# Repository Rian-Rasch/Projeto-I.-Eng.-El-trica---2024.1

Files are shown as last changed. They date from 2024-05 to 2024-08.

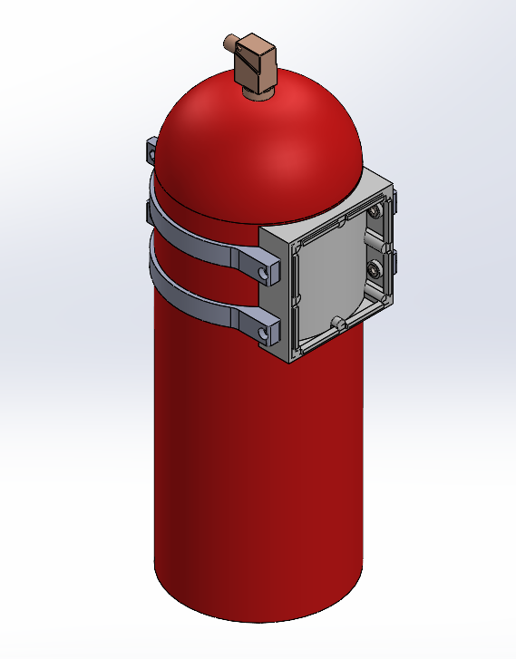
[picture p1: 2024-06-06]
Imagens Guia/Montagem com abraçadeiras.PNG

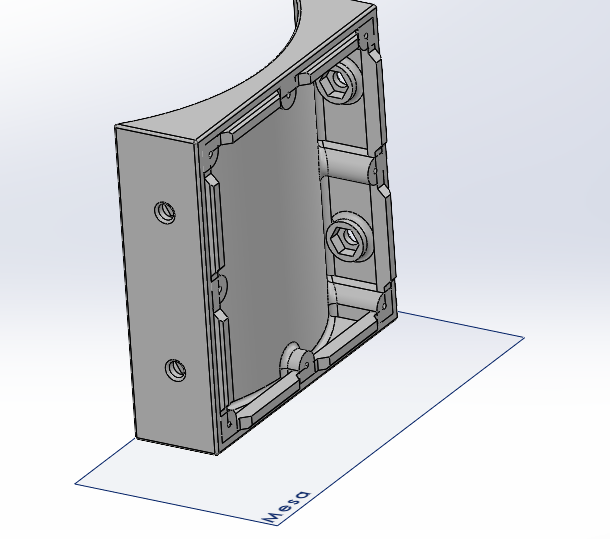
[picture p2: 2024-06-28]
Modelagens/envio para impressão/EXA104/Sentido de impressão.PNG

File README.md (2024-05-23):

# Project I. Electrical Engineering | 2024.1
# Development of an Automatic Fire Extinguisher System with Fire Detection

## Introduction:
This project is developed as part of the Integrative Project course. The main objective is to design and implement an automatic fire extinguisher system capable of detecting fires using Arduino, with the aim of improving traditional fire-fighting systems.

## Objectives:
1. Design an automatic fire extinguisher system capable of accurately and quickly detecting fires using Arduino.
2. Develop an automatic extinguishing mechanism that is effective in suppressing fires.
3. Evaluate the effectiveness and technical feasibility of the system in different fire scenarios.

## Methodology:
To achieve the proposed objectives, the following steps were adopted:
1. Literature review to understand the principles of fire detection and existing automatic extinguishing systems.
2. Conceptual design of the system, considering detection requirements, extinguishing agents, and system integration using Arduino.
3. Implementation of the system in a laboratory environment, using Arduino, fire detection sensors, and extinguishing mechanisms.
4. Testing and analysis to evaluate the effectiveness of the system under different fire conditions.

## Expected Results:
It is expected that this project will result in an effective, reliable, and economically viable automatic fire extinguisher system based on Arduino. Additionally, it aims to contribute to the advancement of fire-fighting technology, offering an innovative solution adaptable to various applications.

## Conclusion:
We believe that this project represents a significant contribution to fire safety, providing a solution that combines advanced fire detection with automatic extinguishing using the Arduino platform. We look forward to sharing our results and discussing potential improvements and future applications.

Thank you for your attention.

---

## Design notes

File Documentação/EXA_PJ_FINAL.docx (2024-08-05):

EXA: Extintor Automático contra

incêndios em quadros elétricos

Rian Rasch PereiraI, Mateus da Rosa TonettoI,

Marcus Vinicius Preira dos SantosI, Theo do Nascimento MoreiraI

I Universidade Federal de Santa Maria, Santa Maria, Rio Grande do Sul, Brasil

RESUMO

Ao pensarmos no combate de incêndios elétricos também estamos examinando perdas humanas, patrimoniais e afetivas, bem como a devastação da fauna e flora locais, graves interrupções no fornecimento de energia e risco iminente de incêndios de maior magnitude. Um ponto crítico, em qualquer infraestrutura são os quadros elétricos, e a instalação de um dispositivo que age com resposta imediata aos incêndios e está diretamente interligado ao sistema elétrico, pode facilitar o combate ao incêndio, minimizando os danos. Por este motivo o presente trabalho tem por objetivo elaborar o dispositivo EXA para a extinção de incêndios automatizada em quadros elétricos. Para isso, foram realizados estudo laboratoriais com Arduino, sensores de temperatura e infravermelho, bem como, a criação de um código.

Palavras-chave: Automação; Extintor; Prevenção a incêndio; Quadro de distribuição; Quadro elétrico

ABSTRACT

When considering the combat of electrical fires, we are also examining human, material, and emotional losses, as well as the devastation of local fauna and flora, severe interruptions in energy supply, and the imminent risk of larger fires. A critical point in any infrastructure is the electrical panels, and the installation of a device that acts with immediate response to fires and is directly interconnected with the electrical system can facilitate fire fighting, minimizing damages. For this reason, the present study aims to develop the EXA device for automated fire extinguishing in electrical panels. To achieve this, laboratory studies were conducted with Arduino, temperature and infrared sensors, as well as the creation of a code.

Keywords: Automation; Extinguisher; Fire Prevention; Electrical Panel; Distributionm Panel;

1 INTRODUÇÃO

A segurança contra incêndios elétricos é uma questão de extrema importância em diversos setores, desde residências até indústrias. A cada ano, milhares de incidentes de incêndios elétricos ocorrem em todo o mundo, resultando em perdas significativas de vidas, propriedades e recursos naturais. Segundo dados da Associação Brasileira de Conscientização para os Perigos da Eletricidade (Abracopel)¹, somente em 2023 foram registrados 963 casos de incêndios elétricos no Brasil, o que evidencia a urgência em desenvolver e implementar medidas eficazes de prevenção e combate a esses eventos.

Neste contexto, o desenvolvimento do Extintor Automático Contra Incêndio em Quadros Elétricos (EXA) representa um novo olhar, com mais atenção para a segurança de sistemas elétricos. O EXA é um dispositivo projetado especialmente para quadros de distribuição, capaz de detectar rapidamente fogo ou calor excessivo e acionar uma descarga de CO2 para extinguir o incêndio de forma automatizada [2].

A presente pesquisa tem como objetivo explorar as características, funcionamento e eficácia do EXA como medida de prevenção e combate a incêndios elétricos em quadros elétricos. Para isso, serão realizados estudos laboratoriais com Arduino, sensores de temperatura e infravermelho, além da análise de dados de ocorrências de incêndios elétricos para embasar empiricamente os resultados obtidos.

2 MATERIAIS E MÉTODOS

Os materiais utilizados para a construção do projeto EXA foram: o Módulo Sensor de Chamas KY-026, o Módulo Sensor de Temperatura KY-028, pequenos condutores, um extintor de CO2 de 6 quilos, um display genérico 16x2 (com IC2), parafusos, três baterias de Lítio 18650, uma placa BMS, um servo motor, conjunto de cabo de aço e conduite, fonte de alimentação bivolt 12V, um quadro elétrico, um Arduino. Além disso com auxílio do programa Solid Works foram modelados: uma Caixa Corpo EXA101 (Anexo 2), a Tampa 1 – Caixa EXA102 (Anexo 3), Tampa 2 – Caixa EXA104 (Anexo 4), 04 braçadeiras EXA301 (Anexo 5), um Suporte Servomotor EXA230 (Anexo 6), uma Polia Motora EXA 231 (Anexo 7), o Suporte Sensores EXA 200 (Anexo 8). Podemos conferir a Montagem Caixa – Tampas no Anexo 8.

Foi utilizado a linguagem de programação C++ e o ambiente laboratorial NUPEDEE do Centro de Tecnologias da Universidade Federal de Santa Maria para criar o código abaixo:

1 #include <Wire.h> // Biblioteca para Comunicação I2C
2 #include <LiquidCrystal_I2C.h> // Biblioteca com as funções do display
3 #include <Servo.h>
5 #define flameSensorPin A0
6 #define tempSensorPin A1
7 #define batterySensorPin A2 // Supondo que o sensor de carga da bateria está conectado ao pino A2
8 #define servoPin 3
10 #define p_temp 60
11 #define p_fogo 200
12 Servo servo;
14 LiquidCrystal_I2C lcd(0x27,20,4); // Inicializa o display no endereço 0x27
16 void setup() {
17 Serial.begin(9600);
18 servo.attach(servoPin);
19 servo.write(0);
20 lcd.init();
21 lcd.begin(16, 2); // Identifica que o display possui 16 colunas e 2 linhas
22 lcd.clear(); // Apaga todos os caracteres do Display
23 lcd.backlight();
24 }
26 int fogo_ir() {
27 if (analogRead(flameSensorPin) < p_fogo) {
28 delay(250);
29 if (analogRead(flameSensorPin) < p_fogo) {
30 return 1;
31 } else return 0;
32 }
33 } else {
34 return 0;
35 }
36 }
38 int fogo_temp() {
39 if (map(analogRead(tempSensorPin), 0, 1023, 125, -55) > p_temp) {
40 delay(250);
41 if (map(analogRead(tempSensorPin), 0, 1023, 125, -55) > p_temp) {
42 return 1;
43 } else {
44 return 0;
45 }
46 } else {
47 return 0;
48 }
49 }
51 void aciona_ext(int flag){
52 int tempo = flag * 1000;
53 servo.write(360);
54 delay (tempo);
55 servo.write(0);
56 }
58 void loop() {
59 int flag = fogo_temp() + fogo_ir();
60 /*
61 Serial.print("Flag = ");
62 Serial.println(flag);
64 Serial.print("Temperatura: ");
65 Serial.print(map(analogRead(tempSensorPin), 0, 1023, 125, -55));
66 Serial.println(" C ");
68 Serial.print("Bat: ");
69 Serial.print(map(analogRead(batterySensorPin), 0, 1023, 0, 100));
70 Serial.println("%");
72 Serial.println();
73 */
74 delay(1000);
76 lcd.clear(); // Apaga todos os caracteres do Display
77 lcd.setCursor(0,0); // Marca o cursor na posição coluna 0, linha 0
78 lcd.print("Temperatura:");
79 lcd.print(map(analogRead(tempSensorPin), 0, 1023, 125, -55));
80 lcd.print("C");
82 lcd.setCursor(0,1); // Marca o cursor na posição coluna 0, linha 1
83 lcd.print("Bat:");
84 lcd.print(map(analogRead(batterySensorPin), 0, 1023, 0, 100));
85 lcd.print("%");
86 lcd.print(" Ir: ");
87 lcd.print(analogRead(flameSensorPin));
88 }

O funcionamento do Projeto consta como na Figura 1. Os sensores acoplados ao quadro de distribuição e ligados a um Arduino, quando detectarem 60 GRAUS, fogo ou infravermelho farão com que o servo motor receba um sinal, sendo ativado e liberando uma descarga de CO2, até que sesse o sinal de fogo (O Extintor tem de 13 a 18 s de funcionamento em abertura total, não sei como inserir isso aqui ). O servo motor é inserido dentro da Caixa de Corpo, que fica integrado ao extintor de incêndio através de duas braçadeiras conforme a Figura 2.

Figura 1 – Diagrama de funcionamento do projeto

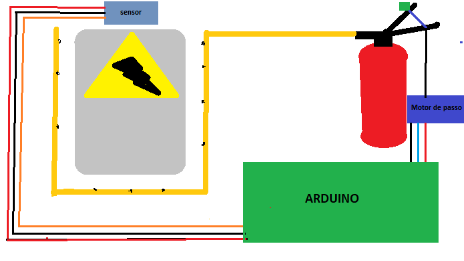
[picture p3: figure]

Fonte: desenvolvida pelos autores

Figura 2 – Ilustração do extintor

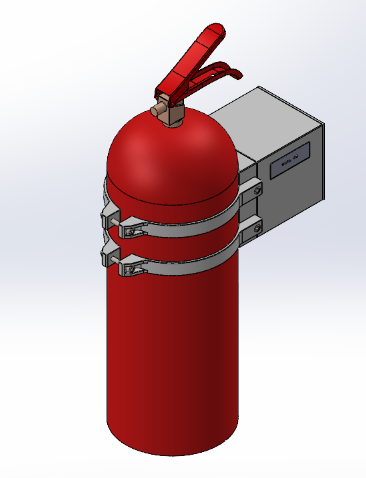
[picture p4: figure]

Fonte: desenvolvido pelos autores

3 RESULTADOS E DISCUSSÃO

BLÁ BLÁ FONTE 12 0.5 DE PARAGRAFO

Colocar foto das coisas montadas

Depois que terminar, salva o PDF e mescla com os anexos

4 CONCLUSÃO

BLÁ BLÁ FONTE 12 0.5 DE PARAGRAFO. Não pode ter referencias aqui, cuidado

REFERÊNCIAS

1 - MARTINHO, Edson; DE SOUZA, Danilo Ferreira; MARTINHO, Meire Biudes; MARTINS JR. Walter Aguiar; MORITA, Lia Hanna Martins; MAIONCHI, Daniela de Oliveira (org). ANUÁRIO ESTATÍSTICO DE ACIDENTES DE ORIGEM ELÉTRICA 2024 – Ano base 2023. Salto-SP: Abracopel, 2023. DOI: 10.29327/

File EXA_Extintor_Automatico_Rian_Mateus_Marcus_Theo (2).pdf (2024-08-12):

# EXA: Extintor Automático contra incêndios em quadros elétricos

Rian Rasch Pereira
Federal University of Santa Maria, UFSM Santa Maria, Brazil
rian.rasch@acad.ufsm.br

Mateus da Rosa Tonetto
Federal University of Santa Maria, UFSM Santa Maria, Brazil
mateus.tonetto@acad.ufsm.br

Theo do Nascimento Moreira Federal University of Santa Maria, UFSM Santa Maria, Brazil
theo.moreira@acad.ufsm.br

Marcus Vinicius Preira dos Santos Federal University of Santa Maria, UFSM Santa Maria, Brazil
marcus.santos@acad.ufsm.br

Resumo — Ao pensarmos no combate de incêndios elétricos também estamos examinando perdas humanas, patrimoniais e afetivas, bem como a devastação da fauna e flora locais, graves interrupções no fornecimento de energia e risco iminente de incêndios de maior magnitude. Um ponto crítico, em qualquer infraestrutura são os quadros elétricos, e a instalação de um dispositivo que age com resposta imediata aos incêndios e está diretamente interligado ao sistema elétrico, pode facilitar o combate ao incêndio, minimizando os danos. Por este motivo o presente trabalho tem por objetivo elaborar o dispositivo EXA para a extinção de incêndios automatizada em quadros elétricos. Para isso, foram realizados estudo laboratoriais com Arduino, sensores de temperatura e infravermelho, bem como, a criação de um código.

Palavras-chaves— | Automação; | Extintor; | Prevenção | a
incêndio; Quadro de distribuição; Quadro elétrico.

Abstract — When considering the combat of electrical fires, we are also examining human, material, and emotional losses, as well as the devastation of local fauna and flora, severe interruptions in energy supply, and the imminent risk of larger fires. A critical point in any infrastructure is the electrical panels, and the installation of a device that acts with immediate response to fires and is directly interconnected with the electrical system can facilitate fire fighting, minimizing damages. For this reason, the present study aims to develop the EXA device for automated fire extinguishing in electrical panels. To achieve this, laboratory studies were conducted with Arduino, temperature and infrared sensors, as well as the creation of a code.

Keywords— Automação; Extintor; Prevenção a incêndio; Quadro de distribuição; Quadro elétrico.

I. INTRODUÇÃO

A segurança contra incêndios elétricos é uma questão de extrema importância em diversos setores, desde residências até indústrias. A cada ano, milhares de incidentes de incêndios elétricos ocorrem em todo o mundo, resultando em perdas significativas de vidas, propriedades e recursos naturais. Somente em 2023 foram registrados 963 casos de incêndios elétricos no Brasil, o que evidencia a urgência em desenvolver e implementar medidas eficazes de prevenção e combate a esses eventos. [1]
Neste contexto, o desenvolvimento do Extintor Automático contra incêndio em quadros elétricos (EXA) representa um novo olhar, com mais atenção para a segurança de sistemas elétricos. Este é um dispositivo projetado especialmente para quadros de distribuição, capaz de detectar rapidamente fogo ou calor excessivo e acionar uma descarga de CO2 para extinguir o incêndio de forma automatizada.
A presente pesquisa tem como objetivo explorar as características, funcionamento e eficácia do EXA como medida de prevenção e combate a incêndios em quadros elétricos, como projeto final da disciplina de Projeto Integrador em Engenharia Elétrica I (UFSM00295) da Universidade Federal de Santa Maria.

II. MATERIAIS E METODOS
Os materiais utilizados para a construção do projeto EXA foram: o Módulo Sensor de Chamas KY-026, o Módulo Sensor de Temperatura KY-028, pequenos condutores, um extintor de CO2 de 6 quilos, um display genérico 16x2 (com IC2), parafusos, três baterias de Lítio 18650, uma placa BMS, um servo motor, conjunto de cabo de aço e conduite, fonte de alimentação bivolt 12V, um quadro elétrico, um Arduino. Além disso com auxílio do programa Solid Works foram modelados: uma Caixa Corpo EXA101 (Anexo 1), a Tampa 1 – Caixa EXA102 (Anexo 2), Tampa 2 – Caixa EXA104 (Anexo 3), 04 braçadeiras EXA301 (Anexo 4), um Suporte Servomotor EXA230 (Anexo 5), uma Polia Motora EXA 231 (Anexo 6), o Suporte Sensores EXA 200 (Anexo 7). Podemos conferir a Montagem Caixa – Tampas (Anexo 8).

O quadro de apresentação foi retirado de uma sucata. Pelas condições do ambiente, havia muita sujeira e o desgaste da tinta. Por isso, foi necessário um reparo estético com tinta spray e uma intensa limpeza no material. Podemos observar na

Fig. 1 o quadro na situação em que foi encontrado e na Fig. 2 o quadro após sua restauração.

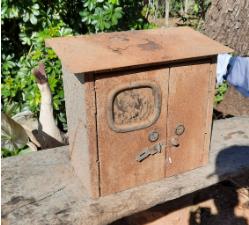
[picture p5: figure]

Fig.1 Quadro antes dos reparos estéticos

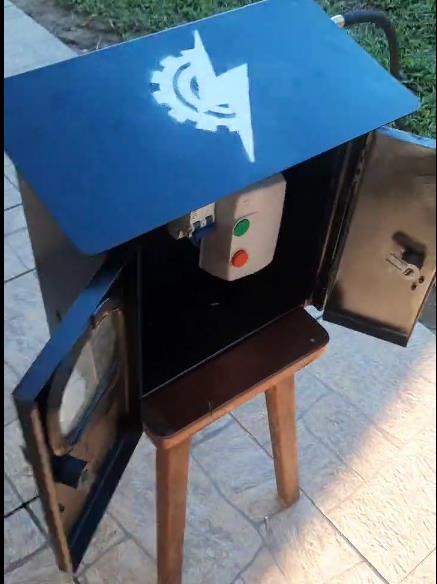
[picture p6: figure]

Fig. 2 Quadro após os reparos estéticos

Foi utilizado a linguagem de programação C++ e o ambiente laboratorial NUPEDEE do Centro de Tecnologias da Universidade Federal de Santa Maria para criar o código abaixo:
1 | #include <Wire.h>
2 | #include <LiquidCrystal_I2C.h>
3 | #include <Servo.h>
4
5 | #define flameSensorPin A0
6 | #define tempSensorPin A1
7 | #define batterySensorPin 2
8 | #define servoPin 3
9
10 | #define p_temp 60
11 | #define p_fogo 200 //0 a 1023
12 | #define abertura 95
13 | Servo servo;
14
15 LiquidCrystal_I2C lcd(0x27,20,4); 16
17 | void setup() {
18 | //Serial.begin(9600);
19 | servo.attach(servoPin);
20 | pinMode(tempSensorPin, INPUT);
21 | pinMode(flameSensorPin, INPUT);
22 | servo.write(0);
23 | lcd.init();
24 | lcd.begin(16, 2); // Identifica que o display
| possui 16 colunas e 2 linhas
25 | lcd.clear(); // Apaga todos os caracteres do
| Display
26 | lcd.backlight();
27 | }
28
29 | int fogo_ir() {
30 | if (analogRead(flameSensorPin) < p_fogo) {
31 | delay(250);
32 | if (analogRead(flameSensorPin) < p_fogo) {
33 | return 1;
34 | } else return 0;
35 | }else return 0;
36 | }
37
38 | int fogo_temp() {
39 | int v_input =
| analogRead(tempSensorPin);//1024
| VALUE
40 | float temp = 125.315-0.175529*v_input-2;
41 | if (temp > p_temp) {
42 | delay(250);
43 | int v_input =
| analogRead(tempSensorPin);//1024
| VALUE
44 | float temp = 125.315-0.175529*v_input-2;
45 | if (temp > p_temp) {
46 | return 1;
47 | } else {

48 | return 0;
49 | }
50 | } else {
51 | return 0;
52 | }
53 | }
54
55 | void aciona_ext1(int flag){
56 | servo.write(abertura);
57 | while(flag !=0){
58 | delay(200);
59 | flag = fogo_temp() + fogo_ir();
60 | }
61 | servo.write(0);
62 | }
63
64 | void aciona_ext2(int flag){
65 | servo.write(abertura);
66 | delay(flag*1000);
67 | servo.write(0);
68 | }
69
70 | void loop() {
71 | int flag = fogo_temp() + fogo_ir();
72 | int v_input =
| analogRead(tempSensorPin);//1024
| VALUE
73 | float temp = 125.315-0.175529*v_input-2;
74
75 | /*
76 | Serial.print("Flag = ");
77 | Serial.println(flag);
78 | Serial.print("Temperatura: ");
79 | Serial.print(temp);
80 | Serial.println(" C ");
81 | Serial.print("IR: ");
82 | Serial.println(analogRead(flameSensorPin));
83 | Serial.print("Bat: ");
84 | Serial.print(map(analogRead(batterySensorP
| in), 0, 1023, 0, 100));
85 | Serial.println("%");
86 | Serial.println();
87 | */
88
89 | lcd.clear();
90 | lcd.setCursor(0,0);
91 | lcd.print("Temp:");
92 | char buffer[10];
93 | dtostrf(temp, 3, 0, buffer);
94 | lcd.print(buffer);
95 | lcd.print("C");
96 | lcd.setCursor(0,1);
97 | lcd.print("Bat:");
98 | dtostrf((2.54 +

### (analogRead(batterySensorPin) /

1023.0) * (4.25 - 2.54))*100/4.25, 3, 0, buffer);
99 | lcd.print(buffer);
100 | lcd.print("%");
101
102 | lcd.setCursor(10,0);
103 | lcd.print("Ir:");
104 | lcd.print(analogRead(flameSensorPin)/100);
105
106 | if(flag != 0){
107 | aciona_ext1(flag);
108 | }
109 | delay(500);
110 | }

Os preços dos itens utilizados no projeto foram avaliados no dia 04/08/2024 no site Mercado Livre a partir dos produtos mais bem avaliados do site. Para a elaboração real do projeto os itens foram comprados via Mercado Livre, com exceção dos que estão indicados na tabela abaixo:

TABELA I

Custo das peças do projeto

* Itens reciclados

Item

Valor

(R$)

Site base

Arduino Uno [2] | 44.99 | Mercado Livre
Servo 180º [3] | 46,99 | Mercado Livre
Conversor DC DC [4] | 21,66 | Mercado Livre
Bms 3s 18650 Li-ion 20 [5] | 12,90 | Mercado Livre
Display 16x2 +i2c [6] | 30,99 | Mercado Livre
Modulo Sensor de Temperatura [7] | 5,90 | ELETROGATE
Modulo Sensor de IR (Chama) [8] | 8,58 | ELETROGATE
3 baterias 18650 [9] | 62,7 | Mercado Livre

Parafusos* [10] | 37,37 | Mercado Livre
Jumpers* [11] | 13,59 | Mercado Livre

Quadro de Apresentação*
[12] | 97,50 | Mercado Livre
Tubulação de CO2 [13] | 173 | Mercado Livre
1kg de Filamento PLA [14] | 112,61 | Mercado Livre
Extintor de CO2 6kg [15] | 700 | Mercado Livre
Molas [16] | 10,299 | Mercado Livre
Total | 1379,079

O funcionamento do Projeto consta como na Fig. 3. Os sensores acoplados ao quadro de distribuição e ligados a um Arduino, quando detectarem 60 °C, fogo ou infravermelho farão com que o servo motor receba um sinal, sendo ativado e liberando uma descarga de CO2, até que sesse o sinal de fogo, com uma janela de funcionamento entre 13s a 18s. O servo motor é inserido dentro da Caixa de Corpo, que fica integrado ao extintor de incêndio através de duas braçadeiras conforme a Fig. 4.

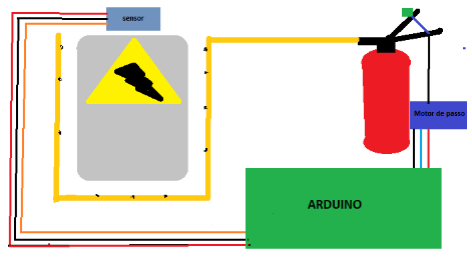
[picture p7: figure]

Fig. 3 Diagrama de funcionamento do projeto

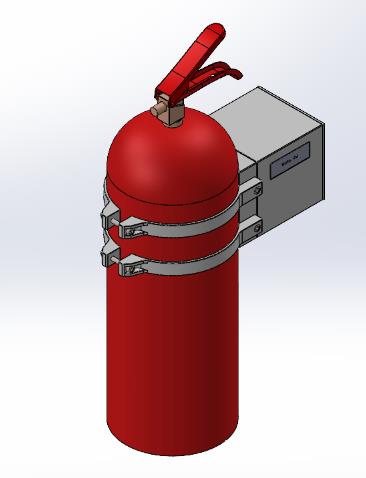
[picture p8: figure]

Fig. 4 Ilustração do extintor

Os demais detalhes podem ser conferidos atráves do https://github.com/Rian-Rasch/Projeto-I.-Eng.-El-trica---2024.1, elabora pelos autores como maneira de organizar as ideias e arquivos do projeto, disponibilizando para que o público conheça mais o projeto EXA.

III. RESULTADOS E DISCUSSÕES

A montagem dos equipamentos do projeto foi concluída com sucesso, como demonstra a Fig. 5. O projeto foi apresentado na 2ª Mostra de protótipos Conceive Design Implement Operate no hall de entrada do Centro de Tecnologias (CT) da UFSM, com duração das 13h30 até às 16h. A percepção do público foi positiva, aguçando a curiosidade para os transeuntes do local. Além da comunidade acadêmica a exposição atraiu convidados, dentre eles, crianças e funcionários da empresa SULCLEAN, como mostra na Fig.
6. O protótipo inclusive foi escolhido pelo público como o segundo mais interessante.

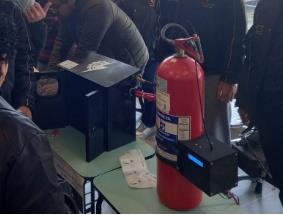
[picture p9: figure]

Fig. 5 Equipamento montado

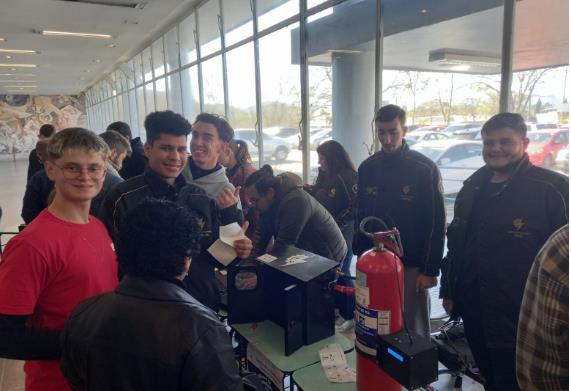
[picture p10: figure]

Fig. 6 Interação com o publico

O seu funcionamento, na Fig. 7 se dá ao acionarmos uma fonte de calor ao quadro, neste caso representado com um isqueiro, após isso o extintor é ativado e dispara uma descarga de CO2, de até, no máximo, 750 milisegundos,

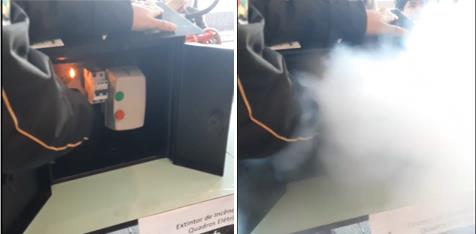
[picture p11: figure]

Fig. 7 EXA em funcionamento

Como limitações do projeto percebe-se que o uso do motor servo dificulta sua elaboração, sendo mais adequado o uso de uma válvula solenoide. Além disso, necessita-se entender o tempo de ação que o extintor deve liberar o CO2 e como deve ser feita a manutenção do EXA com mais estudos.

O projeto contribui significativamente para a disseminação do tema de prevenção de incêndios ao promover uma abordagem inovadora, desenvolvida por estudantes dos primeiros semestres do curso de Engenharia Elétrica. Além disso, este projeto estabelece uma base sólida para o aprofundamento e continuidade das propostas desenvolvidas. Recomenda-se a continuidade e expansão do trabalho nas disciplinas subsequentes, como Projeto Integrador em Engenharia Elétrica II (UFSM000296) e Projeto Integrador em Engenharia Elétrica III (UFSM00297). Em caso de continuidade seria interessante adquirir a patente do projeto, transformando-o em um produto.

IV. CONCLUSÃO

O desenvolvimento deste projeto demonstrou a viabilidade de criar um sistema eficiente e especializado para a prevenção e combate a incêndios em instalações elétricas, onde a rápida resposta é essencial para evitar danos. O sistema automatizado proposto é capaz de detectar e extinguir incêndios em seus estágios iniciais, garantindo maior segurança para pessoas e equipamentos.

Durante | a | implementação, | foi | possível | integrar
conhecimentos | de | diversas | áreas, | como | eletrônica,
programação e sistemas de controle, resultando em um protótipo funcional e eficaz. Os testes realizados comprovaram a rapidez e eficiência do sistema em situações de risco, validando a proposta inicial e sua aplicabilidade em ambientes com quadros elétricos.

Apesar dos resultados promissores, há espaço para melhorias, como a otimização dos sensores de detecção e a expansão da área de cobertura. Futuras pesquisas poderiam focar na integração do sistema com redes de comunicação inteligentes, permitindo monitoramento remoto.

Outro ponto a ser destacado é a possibilidade de otimizar as modelagens para torná-las mais enxutas, promovendo uma economia de plástico e, consequentemente, reduzindo o impacto ambiental do produto. Esse ajuste não só contribui para a sustentabilidade, como também pode diminuir os custos de produção.

Em suma, o projeto oferece uma contribuição significativa para a segurança em instalações elétricas e segurança contra incêndio apresentando uma solução tecnológica inovadora e adaptável. Com melhorias, o sistema poderá se tornar ainda mais robusto e eficiente, atendendo às necessidades específicas de diversos ambientes.

REFERENCES

[1] Edson Martinho, Danilo Ferreira de Souza, Meire Biudes Martinho, Walter Aguiar Martins Jr., Lia Hanna Martins Morita, and Daniela de Oliveira Maionchi (Eds.), Anuário Estatístico de Acidentes de Origem Elétrica 2024 – Ano Base 2023. Abracopel, Salto-SP, Brazil, 2023. DOI: 10.29327/.
[2] Mercado Livre, Placa Uno Rev3 R3 Atmega328 SMD + Cabo USB +
Pinos, | available | at: | https://produto.mercadolivre.com.br/MLB-
1627447986-placa-uno-rev3-r3-atmega328-smd-cabousbpinos_JM#position%3D21%26search_layout%3Dgrid%26type%3Di tem%26tracking_id%3Dc8ede250-7013-41a8-948f-baad129ef6ca,** (https://produto.mercadolivre.com.br/MLB-1627447986-placa-uno-rev3-r3-atmega328-smd-cabo-usbpinos_JM) accessed on: Aug. 4, 2024.
[3] Mercado Livre, Servo Motor MG996R Metal Gear 180° Melhor Que
TowerPro | MG995, | available | at:
https://produto.mercadolivre.com.br/MLB-4181052988-servo-motormg996r-metal-gear-180melhor-que-towerpro-mg995-_JM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,** accessed on: Aug. 4, 2024.
[4] Mercado Livre, Conversor DC-DC Buck Boost 2 em 1 Step Up e Down
XL6019, | available | at: | https://produto.mercadolivre.com.br/MLB-
2921672108-conversor-dc-dc-buck-boost-2-em-1-step-up-e-downxl6019-_JM?quantity=2,** (https://produto.mercadolivre.com.br/MLB-2921672108-conversor-dc-dc-buck-boost-2-em-1-step-up-e-down-xl6019-_JM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) accessed on: Aug. 4, 2024.
[5] Mercado Livre, Proteção 3S BMS para 3 Baterias 18650 Li-ion 20A 64x20x3.4mm, available at: https://produto.mercadolivre.com.br/MLB-2613729095-proteco-3s-bms-para-3-baterias-18650-li-ion-20a-64x20x34mm-_JM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,** accessed on: Aug. 4, 2024.
[6] Mercado Livre, Display LCD 16x2 1602 Fundo Azul Módulo I2C
Soldado | Arduino, | available | at:
https://www.mercadolivre.com.br/display-lcd-16x2-1602-fundo-azulmodulo-i2c-soldadoarduino/p/MLB29525771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,** (https://www.mercadolivre.com.br/display-lcd-16x2-1602-fundo-azul-modulo-i2c-soldado-arduino/p/MLB29525771) accessed on: Aug. 4, 2024.
[7] Eletrogate, Módulo Sensor de Temperatura com NTC 10K, available at: https://www.eletrogate.com/modulo-sensor-de-temperatura-comntc10k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[MC4]_[G]_[PMax]_ArduinoRoboticaSensoresModuloss&utm_content=&utm_term=&gad_source=1&gclid=Cj0KCQjwwuG1BhCnA RIsAFWBUC3Bn3XfUxe8JBrmKTiLWVqjl3NTpunooEabUVdBdKZs NLXn_eyCfDwaAuFQEALw_wcB,** accessed on: Aug. 4, 2024.
[8] Eletrogate, Sensor de Obstáculos Reflexivo Infravermelho, available at: https://www.eletrogate.com/sensor-de-obstaculo-reflexivoinfravermelho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[MC4]_[G]_[PMax]_ArduinoRoboticaSensoresModuloss&utm_content=&utm_term=&gad_source=1&gclid=Cj0KCQjwwuG1BhCnARIsAFWBUC2DWJ6UmRz86CijTRssHkTJTI-22wQx_cFvee0wm0sfGjHMQvk7F0aAqi_EALw_wcB,** accessed on: Aug. 4, 2024.

[9] Mercado Livre, 3.7V 2600mAh Li-ion 18650 Bateria com Cabo SMP02, available at: https://produto.mercadolivre.com.br/MLB-2000059937-37v-2600mah-li-ion-18650-bateria-com-cabo-smp02-_JM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,** (https://produto.mercadolivre.com.br/MLB-2000059937-37v-2600mah-li-ion-18650-bateria-com-cabo-smp02-_JM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) accessed on: Aug. 4, 2024.
[10] Mercado Livre, Parafuso Chipboard Phillips P/ Madeira 4x20 Caixa 500 Pçs, available at: https://produto.mercadolivre.com.br/MLB-1589407030-parafuso-chipboard-phillips-p-madeira-4x20-caixa-500-pcs-
_JM#position%3D19%26search_layout%3Dgrid%26type%3Ditem%26t racking_id%3D6e02f558-2d44-4b85-8440-17fa6a808221,** (https://produto.mercadolivre.com.br/MLB-1589407030-parafuso-chipboard-phillips-p-madeira-4x20-caixa-500-pcs-_JM) accessed on: Aug. 4, 2024.
[11] Mercado Livre, Kit Cabo Jumper Macho X Fêmea 40 Pçs 20cm para Protoboard, available at: https://www.mercadolivre.com.br/kit-cabojumper-macho-x-fmea-40pcs-20cm-paraprotoboard/p/MLB27997410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 &ad_position=2&ad_click_id=MDc0NGM0NDUtYjQwOS00N2UxLW IyZjYtZWUyYzQ4ZjMyMjlm,** (https://www.mercadolivre.com.br/kit-cabo-jumper-macho-x-fmea-40pcs-20cm-para-protoboard/p/MLB27997410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) accessed on: Aug. 4, 2024.
[12] Mercado Livre, Caixa Padrão Ampla Medidor Monofásico Ampla TAF
N.2, | available | at: | https://produto.mercadolivre.com.br/MLB-
3640294011-caixa-padro-ampla-medidor-monofasico-ampla-taf-n2-_JM#position%3D47%26search_layout%3Dstack%26type%3Ditem%2 6tracking_id%3Db468797c-942a-4a44-bafb-88f6bb21e98f,** (https://produto.mercadolivre.com.br/MLB-3640294011-caixa-padro-ampla-medidor-monofasico-ampla-taf-n2-_JM) accessed on: Aug. 4, 2024.
[13] Mercado Livre, Tubo Alumínio 1/2 Polegada 20 m Refrigeração ou
Chopeiras, | available | at: | https://www.mercadolivre.com.br/tubo-
aluminio-12-polegada-20-m-refrigeraco-ouchopeiras/p/MLB29646663#searchVariation%3DMLB29646663%26po sition%3D2%26search_layout%3Dgrid%26type%3Dproduct%26trackin
g_id%3D29216315-158e-4c91-90d4-1e40935ee7a3,** (https://www.mercadolivre.com.br/tubo-aluminio-12-polegada-20-m-refrigeraco-ou-chopeiras/p/MLB29646663) | accessed | on:
Aug. 4, 2024.
[14] Mercado Livre, Voolt3D PLA Preto Velvet 1 kg 1.75 mm 1 Unidade, available at: https://www.mercadolivre.com.br/voolt3d-pla-pla-pretovelvet-1-kg-175-mm-1-
unidad/p/MLB24741975#searchVariation%3DMLB24741975%26positi on%3D3%26search_layout%3Dgrid%26type%3Dproduct%26tracking_i d%3D6c962cdf-e14d-44a5-a63d-0a68aa3f3dda,** (https://www.mercadolivre.com.br/voolt3d-pla-pla-preto-velvet-1-kg-175-mm-1-unidad/p/MLB24741975) accessed on: Aug. 4, 2024.
[15] Mercado Livre, Extintor CO2 6kg com Placa e Suporte para Parede, available at: https://produto.mercadolivre.com.br/MLB-4854857298-extintor-co2-6kg-placa-suporte-parede-_JM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 mZjAtOTNjYjBiMmY0Nzc2,** (https://produto.mercadolivre.com.br/MLB-4854857298-extintor-co2-6kg-placa-suporte-parede-_JM) accessed on: Aug. 4, 2024.
[16] Mercado Livre, Kit com 20 Molas de 18 cm para Cama Elástica (305-366m, 427m), available at: https://www.mercadolivre.com.br/kit-20-molas-18-cm-para-cama-elastica-305-366m-427m/p/MLB28551592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 &ad_position=1&ad_click_id=NjVkYjhkZGYtMmE3YS00M2U2LTk1
MjAtNzg3OTUyN2RlYzhh,** | accessed | on: | Aug. | 4, | 2024.

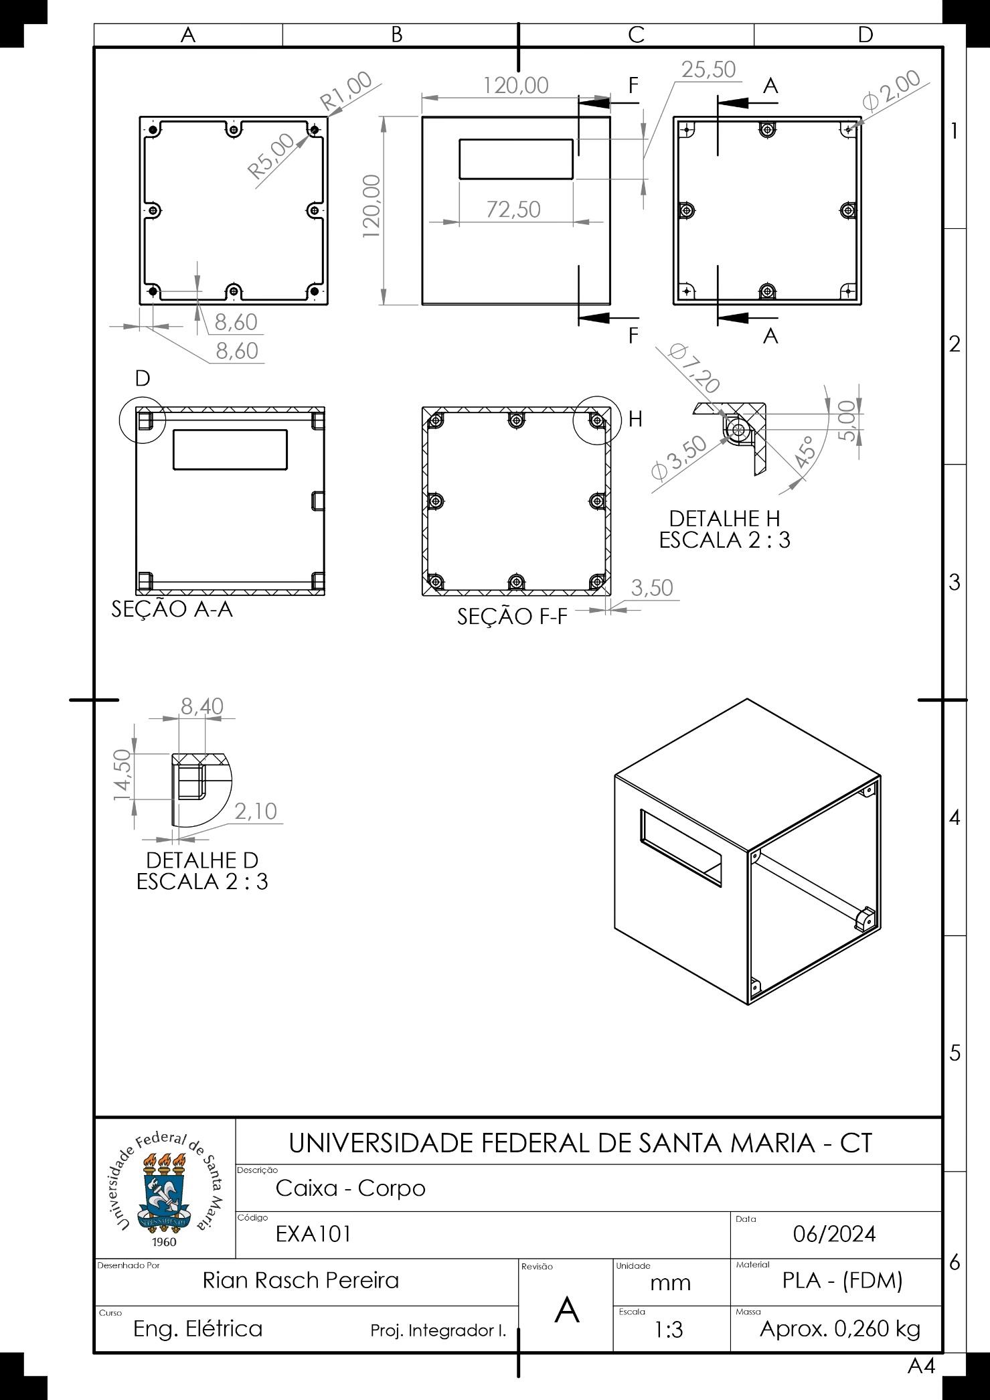
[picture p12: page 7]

### ANEXO 1 – CAIXA CORPO EXA101

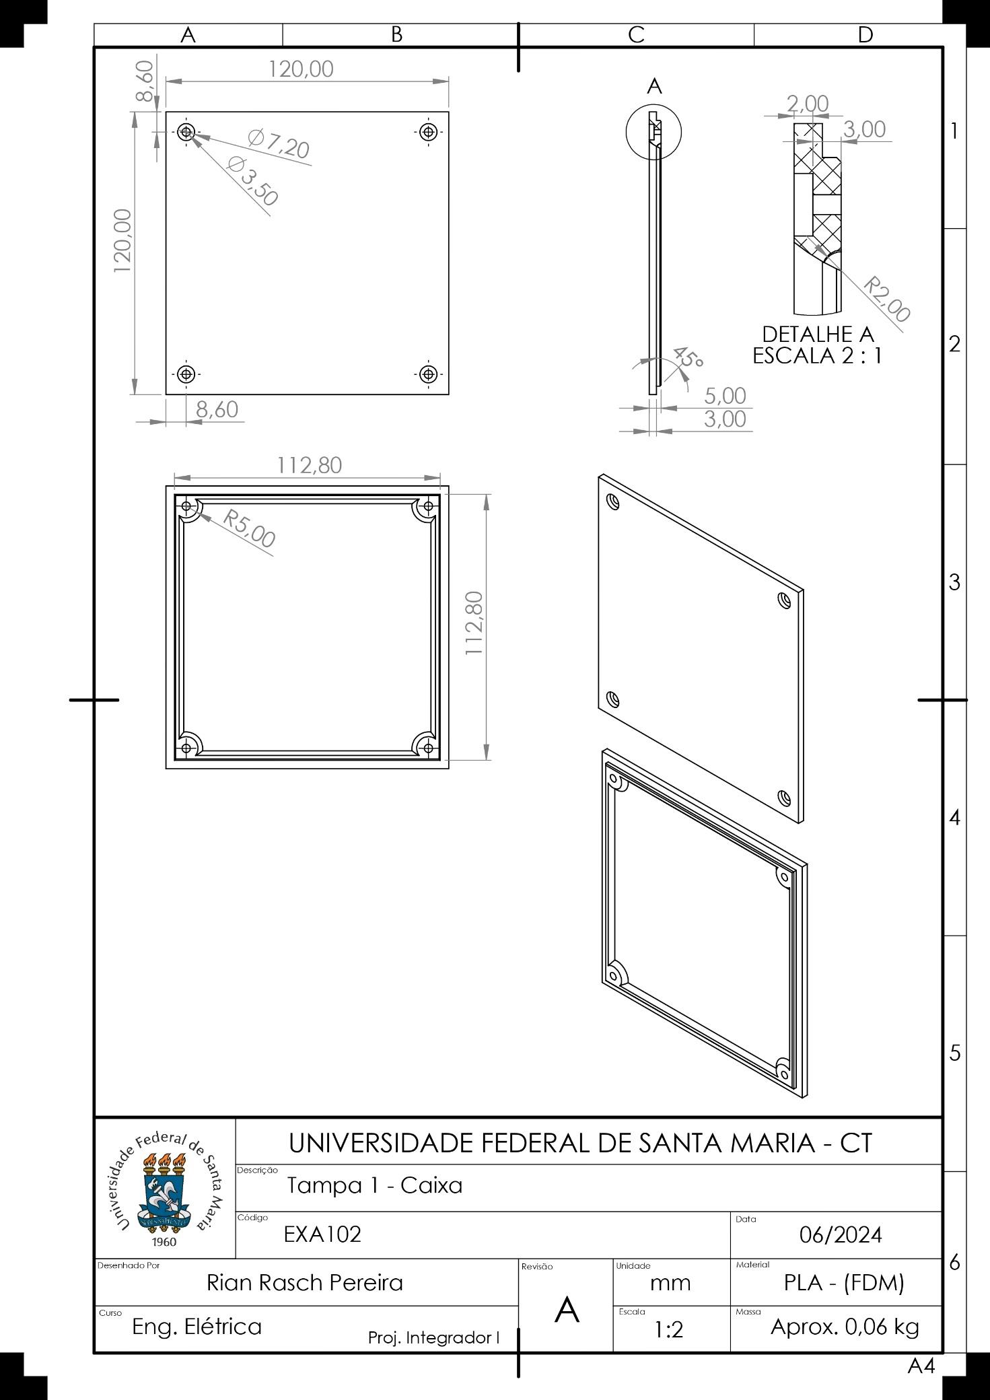
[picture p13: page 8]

### ANEXO 2 – TAMPA 1- CAIXA EXA102

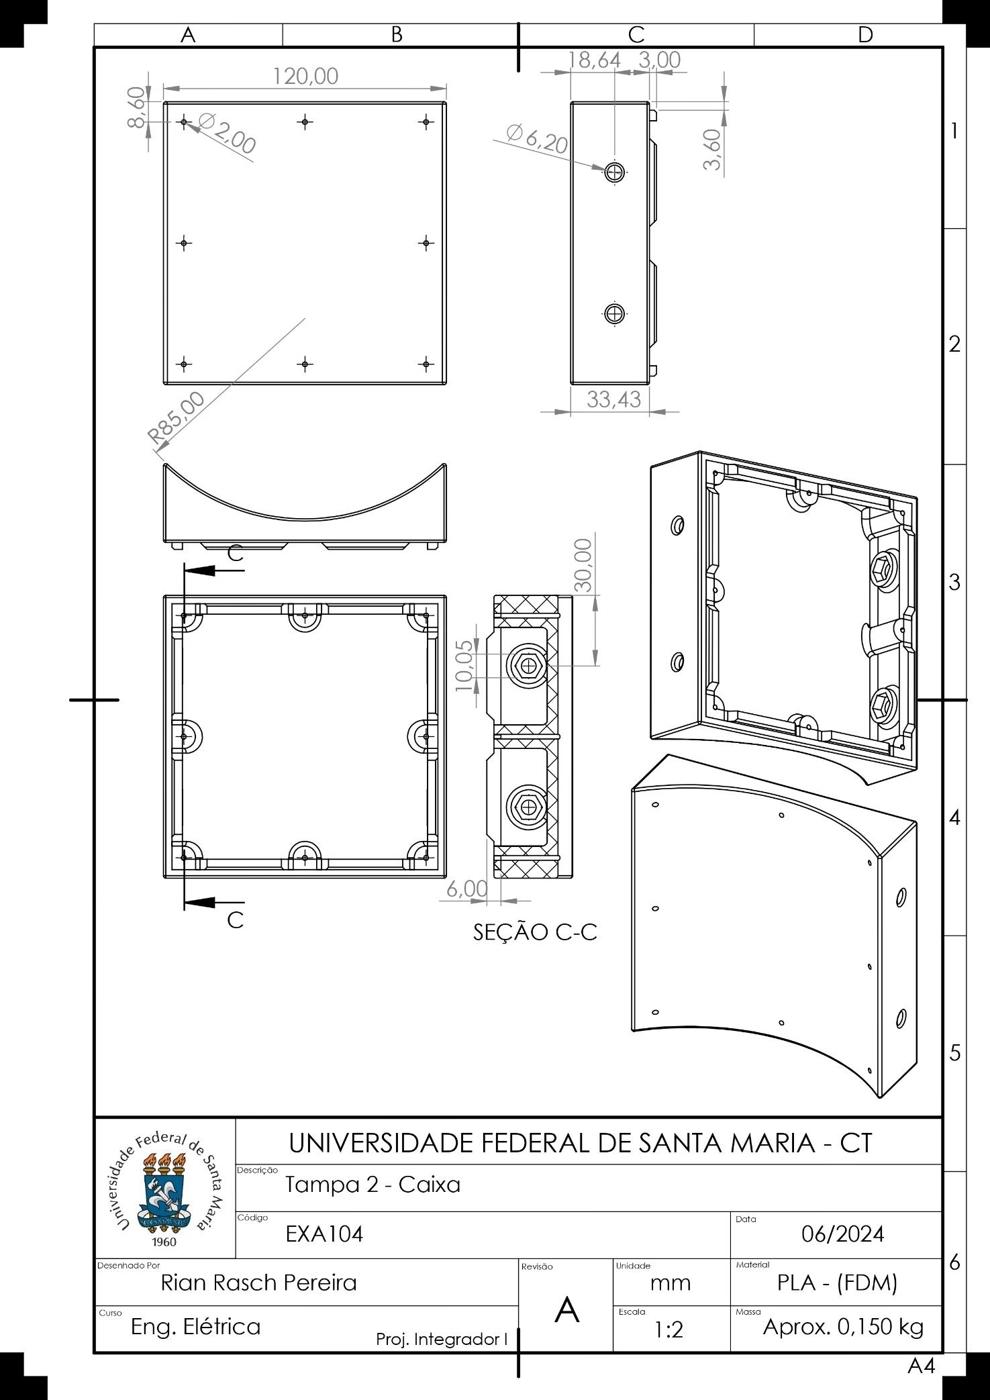
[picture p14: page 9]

### ANEXO 3 – TAMPA 2 CAIXA EXA104

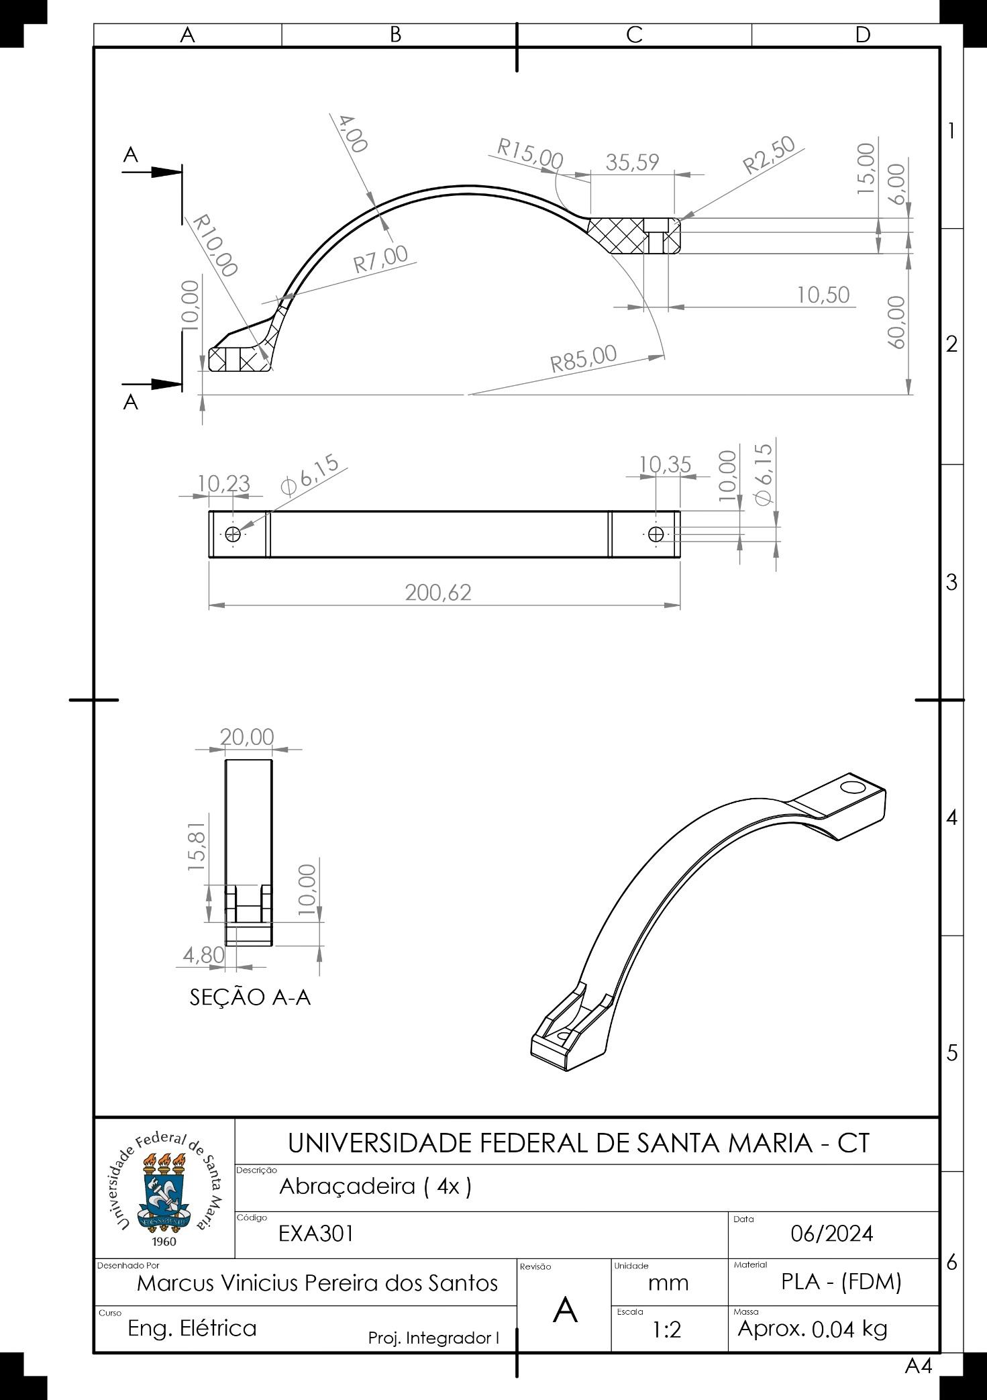
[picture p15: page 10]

### ANEXO 4 – 04 BRAÇADEIRAS EXA301

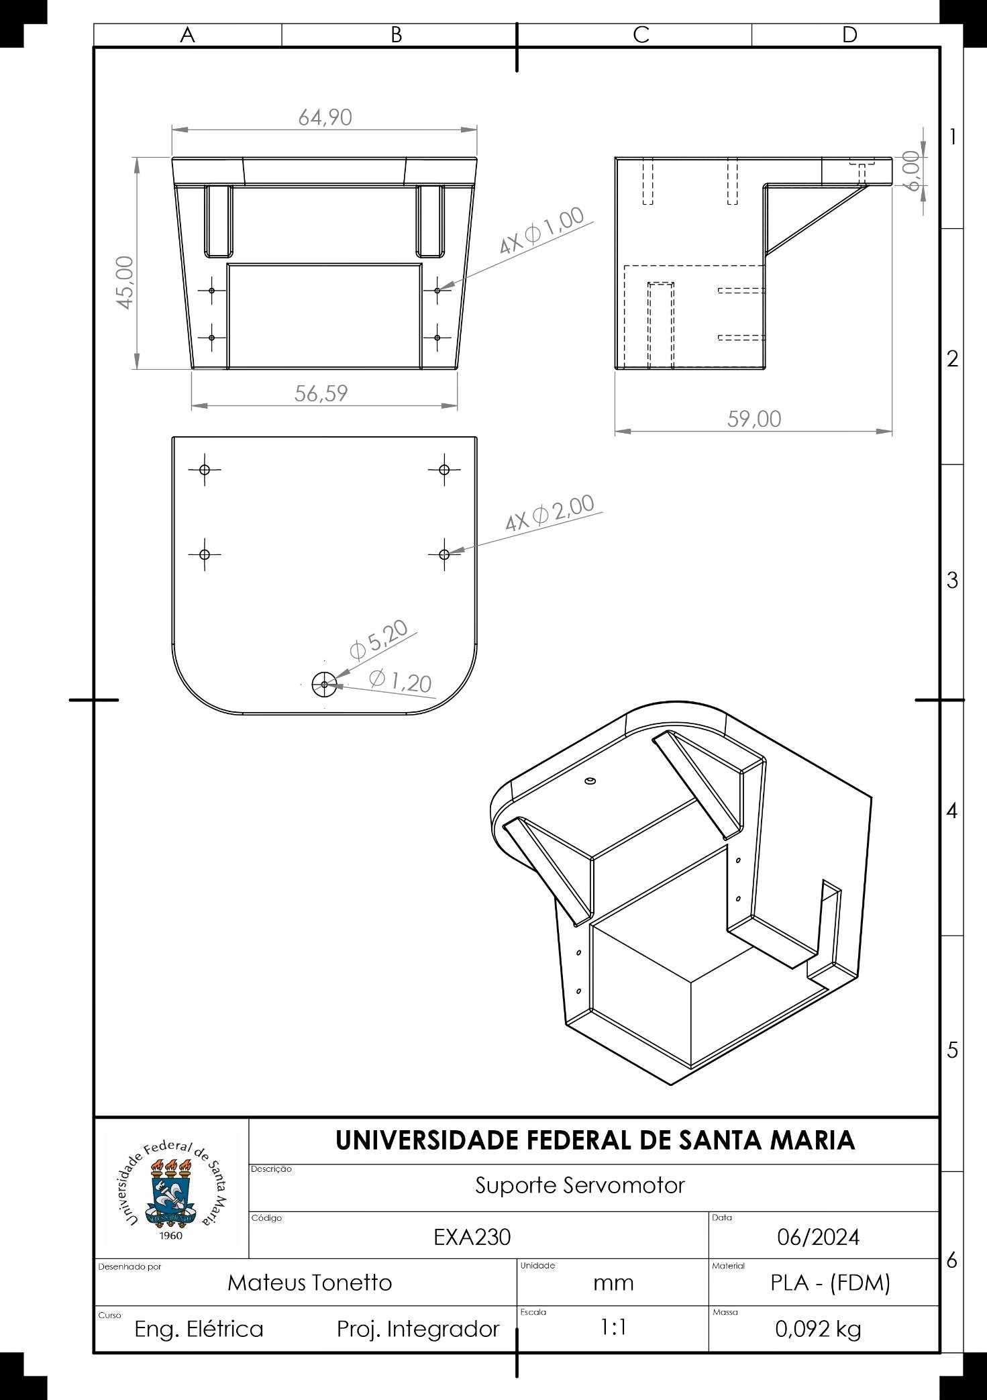
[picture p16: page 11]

ANEXO 5 – SUPORTE SERVOMOTOR EXA230

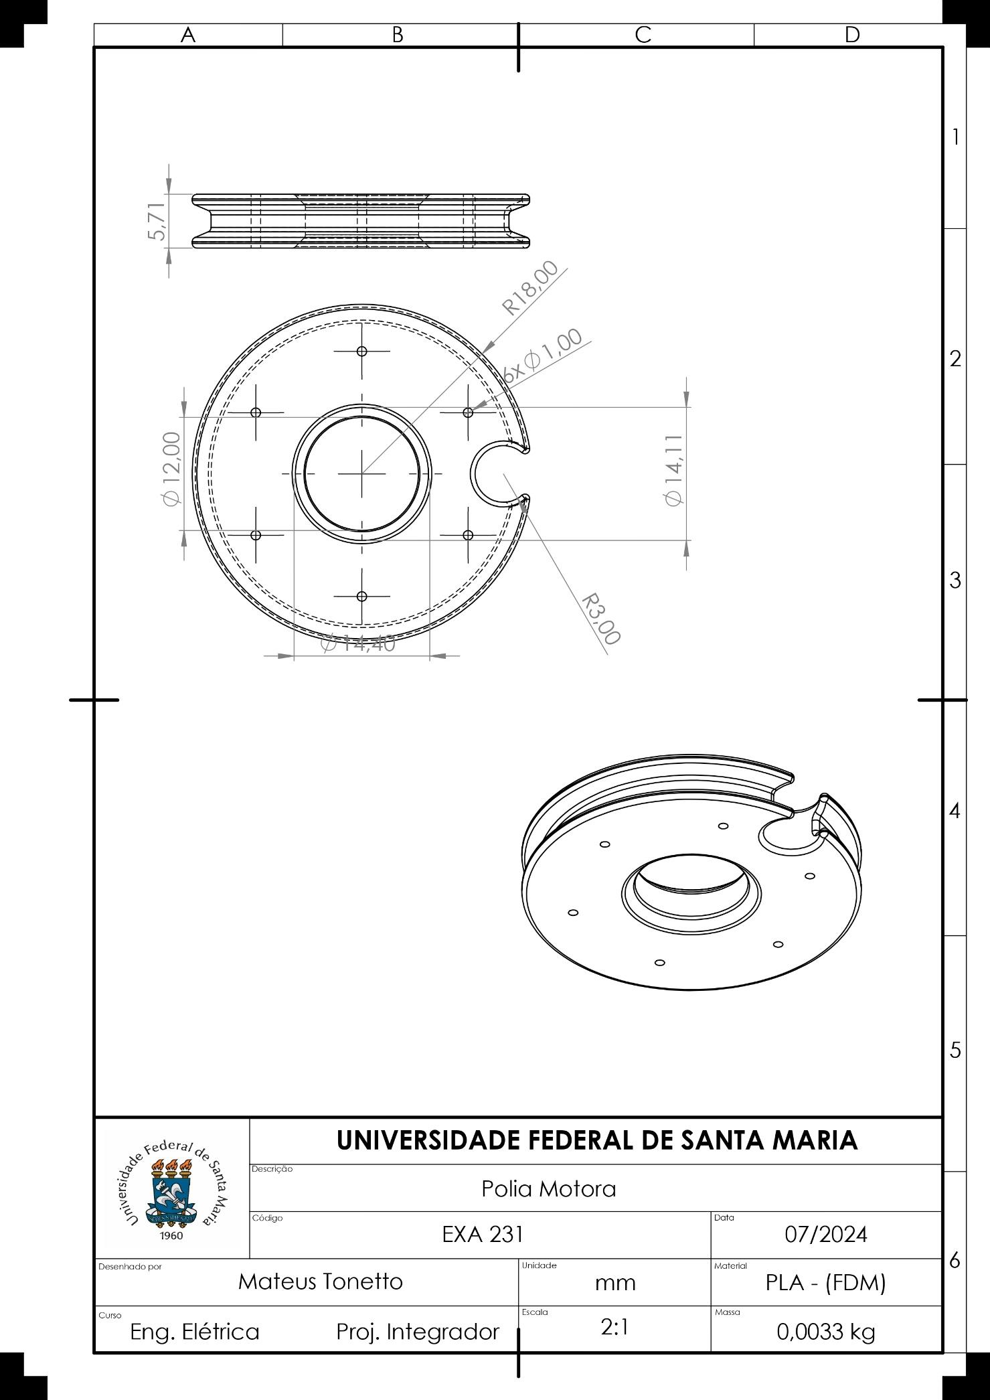
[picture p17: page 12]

### ANEXO 6 – POLIA MOTORA EXA 231

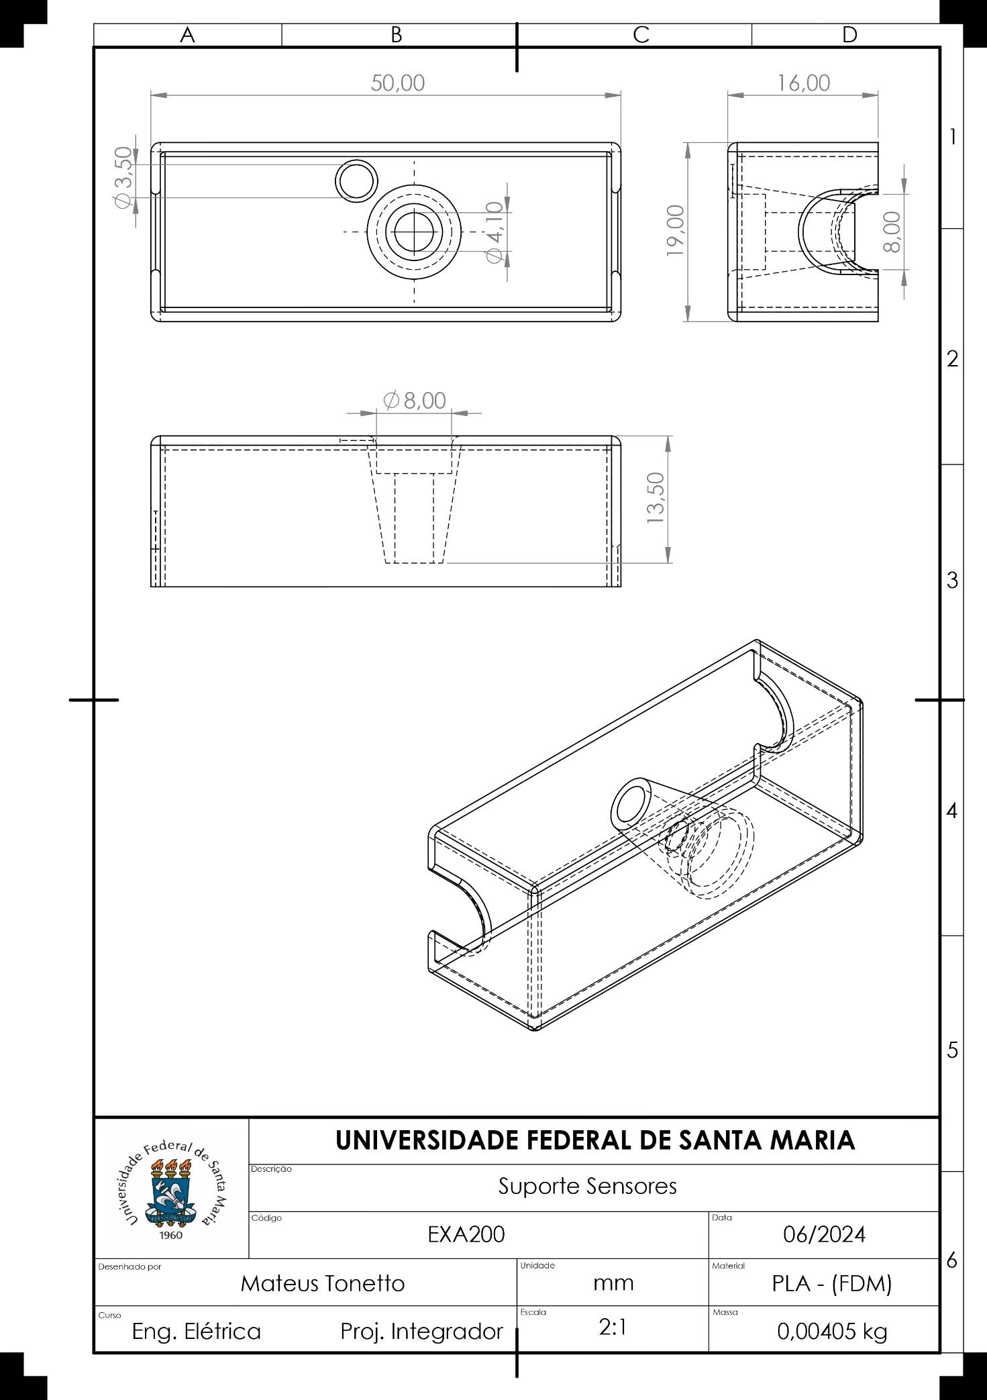
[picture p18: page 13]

ANEXO 7 – SUPORTE SENSORES EXA 200

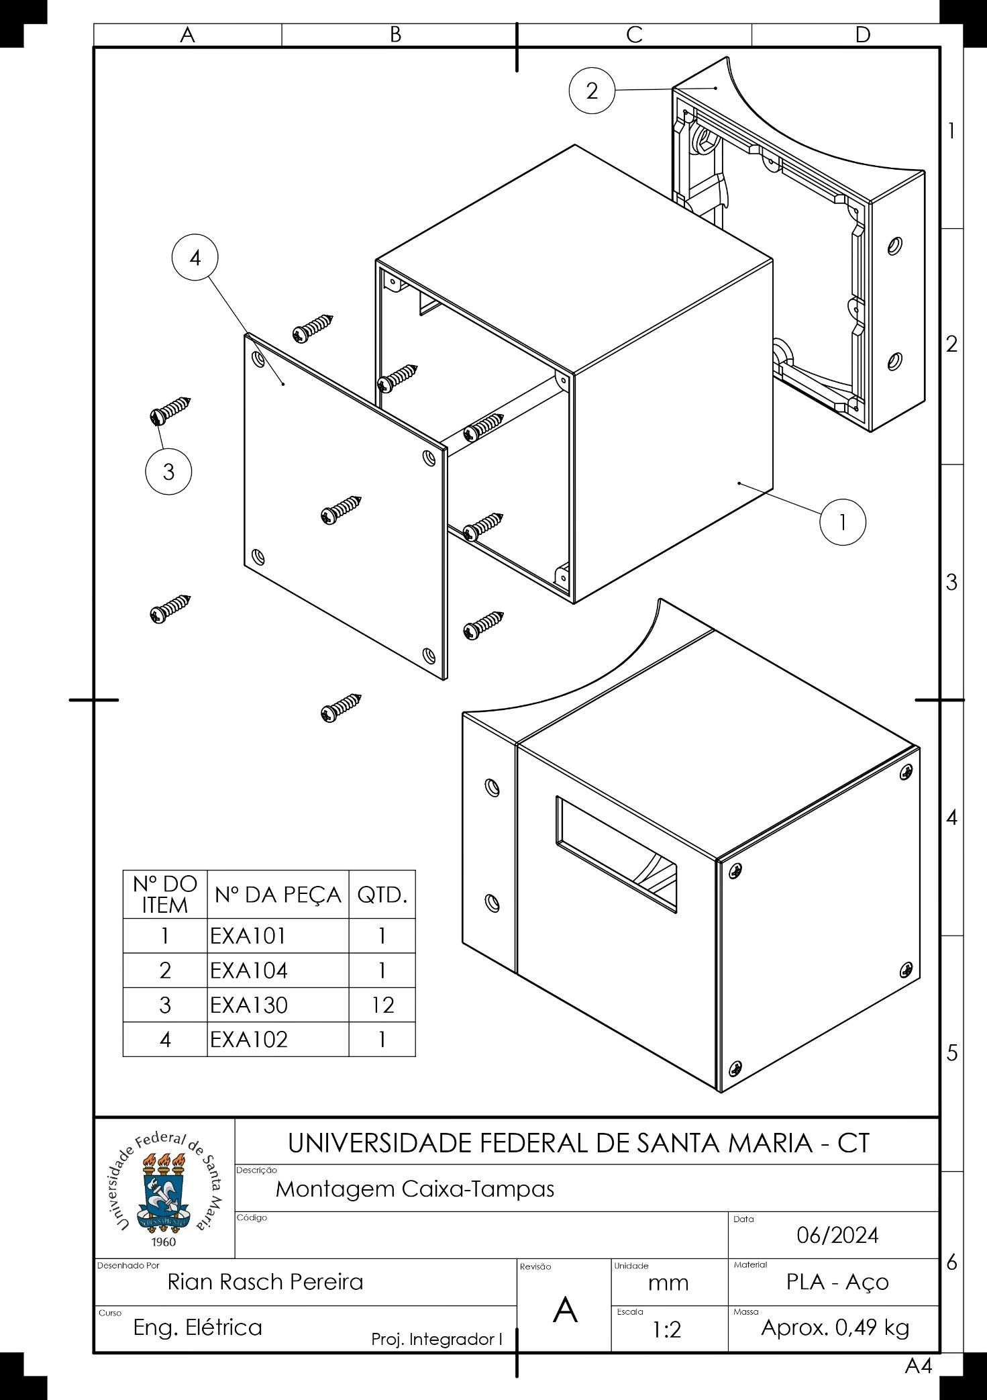
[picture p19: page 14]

ANEXO 8 – MONTAGEM CAIXA – TAMPAS

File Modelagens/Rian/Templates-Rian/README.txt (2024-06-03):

Sufixo do nome dos arquivos: 
Template(Tipo)__(Tamanho em caso de template de desenho)__(Unidades de grandeza)__(versão)

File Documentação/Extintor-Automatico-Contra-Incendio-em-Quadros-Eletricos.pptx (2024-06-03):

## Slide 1

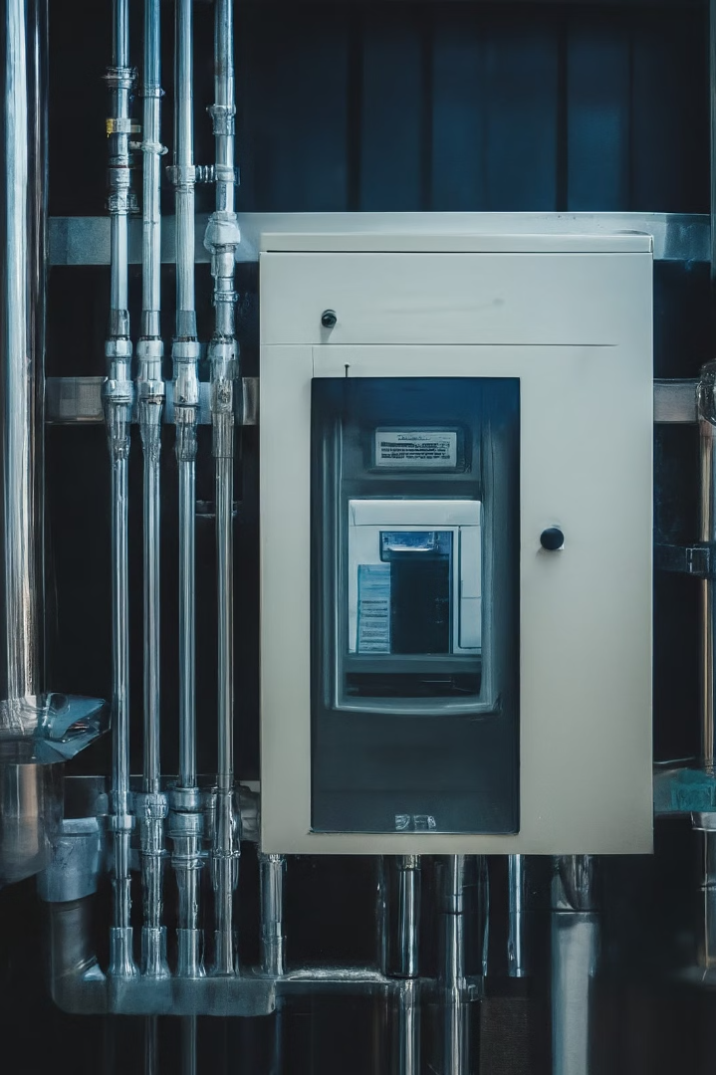
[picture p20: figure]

Extintor Automático Contra Incêndio em Quadros Elétricos

Um extintor de incêndio automático específico para quadros elétricos é um dispositivo que detecta fogo ou calor excessivo dentro de painéis elétricos e ativa automaticamente um sistema de extinção apropriado para apagar o incêndio, sem causar danos aos componentes elétricos.

by rian rasch

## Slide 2

Por que Usar um Extintor Automático?

Prevenção de Danos Maiores

O sistema de extinção automática evita que o incêndio se espalhe e cause danos ainda mais graves.

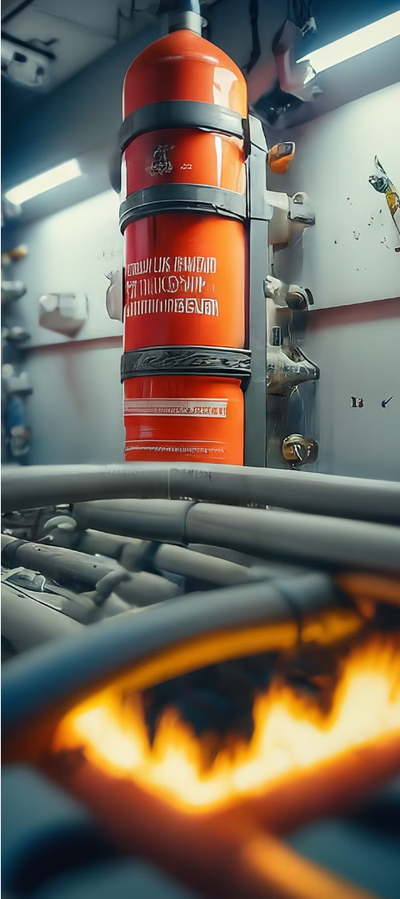
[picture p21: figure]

1

Resposta Imediata

O extintor automático garante uma resposta imediata a incêndios, minimizando os danos e garantindo a segurança.

2

Proteção Crítica

Quadros elétricos são pontos críticos em qualquer infraestrutura, e um incêndio neles pode causar interrupções graves no fornecimento de energia e danos significativos aos equipamentos.

3

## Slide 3

Como Funciona o Extintor Automático?

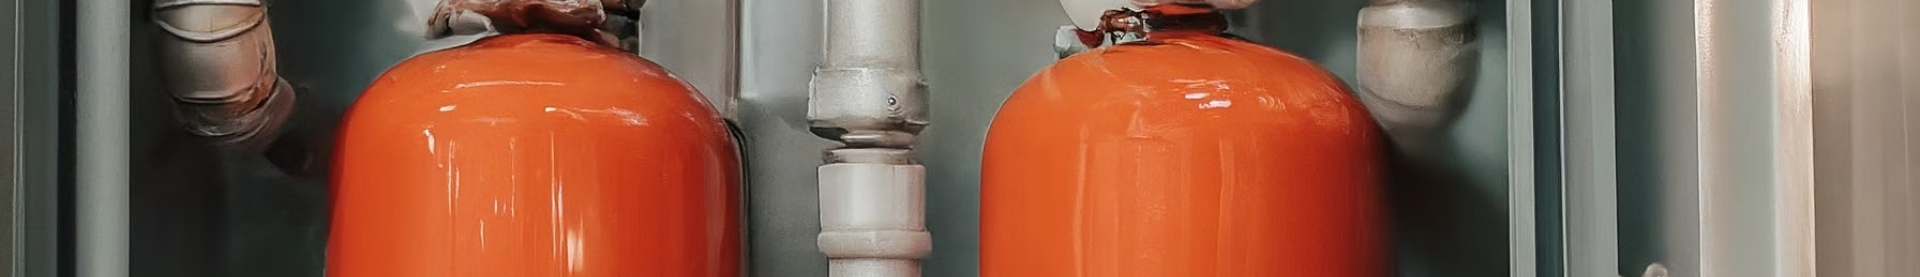
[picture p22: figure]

Detecção

Sensores de calor e infravermelho monitoram constantemente o ambiente interno do quadro elétrico para sinais de incêndio.

Extinção

O extintor libera um agente extintor apropriado, geralmente CO2, que não conduz eletricidade e não danifica os componentes elétricos.

1

2

3

Ativação

Quando os sensores detectam condições indicativas de um incêndio, enviam um sinal para ativar o sistema de extinção.

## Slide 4

Quando e Como o Extintor é Ativado?

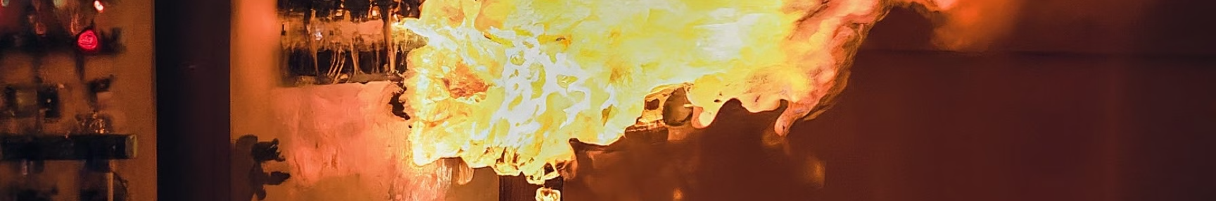
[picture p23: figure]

Detecção Rápida

O sistema de detecção reage rapidamente, ativando o extintor em poucos segundos após a detecção de um incêndio.

Contenção Imediata

A resposta rápida do extintor contém o incêndio antes que ele cause danos significativos ao quadro elétrico.

Prevenção de Danos

O extintor automático evita que o incêndio se espalhe e cause interrupções graves no fornecimento de energia.

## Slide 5

Componentes do Extintor Automático

Sensores

Sensores de calor e infravermelho específicos para ambientes elétricos, que monitoram constantemente o quadro.

Ativação

Mecanismo eletromecânico que libera o agente extintor quando os sensores detectam um incêndio.

Agente Extintor

Gases como CO2, que são eficazes na extinção de incêndios e não causam danos aos componentes elétricos.

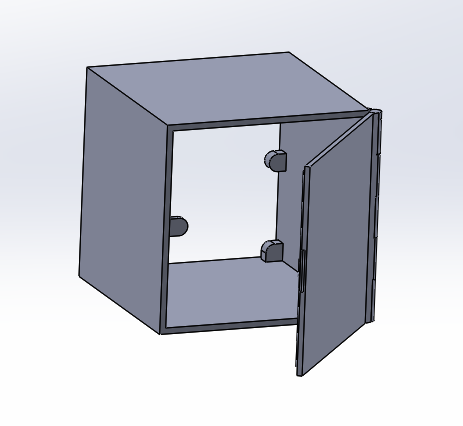
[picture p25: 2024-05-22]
Imagens Guia/Caixa.png

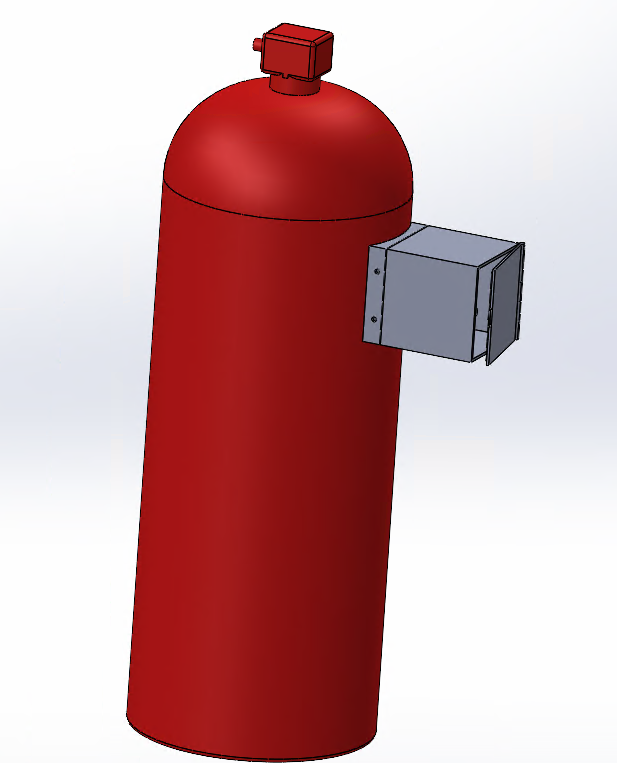
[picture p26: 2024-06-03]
Imagens Guia/Prototipo.PNG

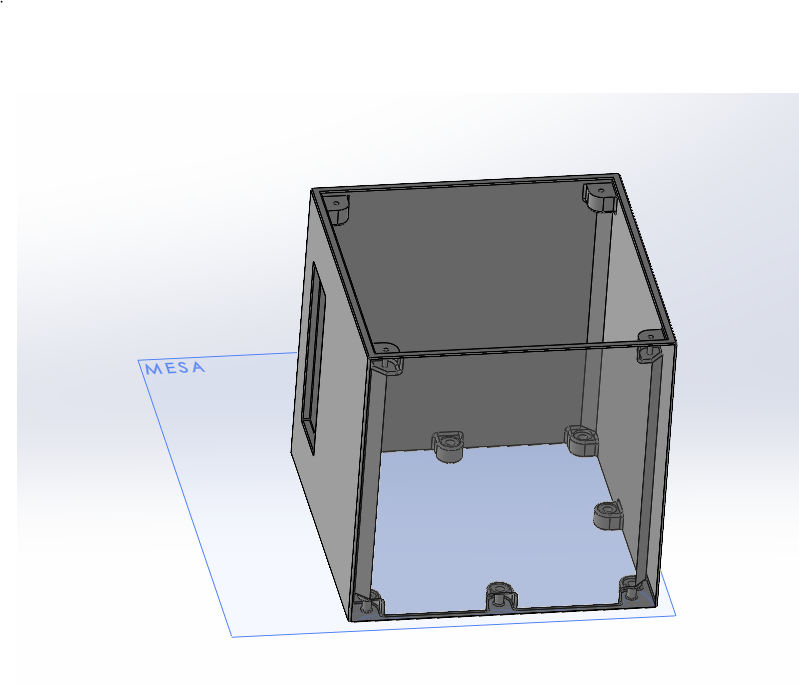
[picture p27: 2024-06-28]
Modelagens/envio para impressão/EXA101/Sentido da Impressão.PNG

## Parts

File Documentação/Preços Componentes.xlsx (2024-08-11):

Descrição | Valor | Obs | Link Acessado em 04/08/2024
Arduino Uno | R$45.00 | Pode ser usado em Stand-Alone | https://produto.mercadolivre.com.br/MLB-1627447986-placa-uno-rev3-r3-atmega328-smd-cabo-usb-pinos-_JM
Servo 180° | R$47.00 |  | https://produto.mercadolivre.com.br/MLB-4181052988-servo-motor-mg996r-metal-gear-180-melhor-que-towerpro-mg995-_JM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
Conversor Dc Dc | R$22.00 |  | https://produto.mercadolivre.com.br/MLB-2921672108-conversor-dc-dc-buck-boost-2-em-1-step-up-e-down-xl6019-_JM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
Bms 3s 18650 Li-ion 20a | R$13.00 |  | https://produto.mercadolivre.com.br/MLB-2613729095-proteco-3s-bms-para-3-baterias-18650-li-ion-20a-64x20x34mm-_JM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
Display 16x2 +i2c | R$31.00 |  | https://www.mercadolivre.com.br/display-lcd-16x2-1602-fundo-azul-modulo-i2c-soldado-arduino/p/MLB29525771
Modulo Sensor de Temperatura | R$5.78 |  | https://www.usinainfo.com.br/sensor-de-temperatura/modulo-chave-termica-sensor-de-temperatura-termistor-arduino-k275-4698.html
Modulo Sensor de IR (Chama) | R$8.58 |  | https://www.usinainfo.com.br/sensor-de-chama-arduino/sensor-de-chama-ky-026-fogo-infravermelho-5mm-2642.html
Parafusos | R$10.00
Jumpers | R$10.00
1kg Filamento PLA | R$112.61 | Utilizado aproximadamente 750g | https://www.mercadolivre.com.br/voolt3d-pla-filamento-premium-1kg-efeito-fosco-cor-preto-velvet/p/MLB24741975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
Molas | R$10.00
Quadro para apresentação | R$100,00 | Usado
3 baterias 18650 | R$61.75 | Usado | https://produto.mercadolivre.com.br/MLB-4035420324-bateria-111v-12v-3s-18650-2600mah-li-ion-sem-pcb-_JM
Extintor Co2 6Kg | R$700.00 | Usado
Tubulação de co2 | R$50.00 | Usado
Soma: | R$1126.72

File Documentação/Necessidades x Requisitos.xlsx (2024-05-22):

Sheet: 1 - Necessidades
Definição das necessidades
Alta confiabilidade
Alta durabilidade
Atratividade tecnológica | Definição das necessidades por clientes / usuários
Baixo consumo de combustível | Clientes e Usuários | Necessidades
Baixo custo de manutenção | Equipe envolvida no projeto | Projeto de baixa complexidade
Baixo peso | Empresa Fabricante | Boa produtividade
Boa Produtividade |  | Dimensões adequadas
Boa resistência mecanica do conjunto |  | Disponibilidade de matéria prima
Combustível automotivo | Vendedor | Preço competitivo
Dimensões adequadas |  | Atratividade tecnológica
Diponibiliade de peças de reposição | Piloto | Baixo consumo de combustível
Fabricação viável |  | Operação facilitada
Fácil acesso a componentes de manutenção |  | Boa resistencia mecânica do conjunto
Manutenção fácil |  | Tracionar aeronave experimental de pequeno porte
Motor de combustão interna |  | Combustível automotivo
Operação Facilitada |  | Alta durabilidade
Preço competitivo |  | Baixo custo de manutenção
Projeto de baixa complexidade |  | Baixo peso
Projeto viável |  | Motor de combustão interna
Seja vendável |  | Alta confiabilidade
Tecnologia moderna | Mecânico | Disponibilidade de peças de reposição
Tracionar aeronave experimental de pequeno porte (até 600kg) |  | Fácilidade de manutenção
Projeto desenvolvido com os recusros disponíveis
Disponibilidade de matéria prima

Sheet: 2 - Requisitos de cliente
Necessidades x requisitos dos clientes
Necessidades | Requisitos de cliente
Alta confiabilidade | Funcionamento estável | A
 | Funcionamento confiável | B
Alta durabilidade | Alta TBO | C
 | Peças com baixo desgaste | D
Atratividade tecnológica | Componentes tecnologicamente confiáveis | E
 | Potência desejada pelo comprador | F
 | Gerenciado por ECU | G
 | motor compacto e alta densidade de potência | H
 | Tecnologia confiável | I
Baixo consumo de combustível | Baixo consumo horário | J
Baixo custo de manutenção | Peças acessíveis no mercado | K
 | Peças com valor adequado | L
 | Fácil manutenção | M
 | Intervalo prolongado entre manutenções | N
Baixo peso | Motor compacto | O
Boa Produtividade | Fácil fabricação | P
 | Processos simplificados | Q
 | Componentes acessíveis | R
Boa resistência mecanica do conjunto | Robusto e durável | S
 | Resistente a altas e baixas temperaturas | T
 | Resistência mecânica e funcional | U
Combustível automotivo | Possibilidade de uso de combustíveis automotivos disponíveis no mercado | V
Dimensões adequadas | altura, largura e comprimento adequado | W
 | flange de hélice compatível com hélices de mercado | X
 | Adequado a uma carenagem de motor para aeronave tandem ou lado a lado | Y
Diponibiliade de peças de reposição | Maioria de peças compatíveis com motores automotivos | Z
 | Peças com preço adequado | AA
Facilidade de manutenção | Componentes disponíveis no mercado | AB
 | Baixo custo dos componentes | AC
 | Mínimo conhecimento de motores exigido | AD
 | Fácil acesso aos componentes | AE
Motor de combustão interna | Queimar combustível líquido | AF
 | Queimar combustível automotivo e de fácil acesso | AG
Operação Facilitada | Sistema de acionamento simplificado | AH
 | Gerenciado eletronicamente | AI
 | Sem controle manual de mistura e ponto | AJ
 | Leitura de parâmetros do motor completa | AK
Preço competitivo | Baixo custo de produção | AL
Projeto de baixa complexidade | Projeto desenvolvido com recursos disoníveis | AM
Tracionar aeronave experimental de pequeno porte | Tração e potência adequada | AN
Disponibilidade de matéria prima | Materia prima disponível e acessível no mercado nacional | AO

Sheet: 2 - Mudge
 |  |  | DIAGRAMA DE MUDGE COMPLETO (utilizado para cálculo) |  |  |  |  |  |  |  |  |  |  |  |  |  |  |  |  |  |  |  |  |  |  |  |  |  |  |  |  |  |  |  |  | Valoração dos requisitos de clientes | Valor de importância
 | Requisitos dos clientes |  | A | B | C | D | E | F | G | H | I | J | K | L | M | N | O | P | Q | R | S | T | U | V | W | X | Y | Z | AA | AB | AC | AD | AE | AF | Total
1 | Funcionamento estável | A | A | B1 | A5 | A3 | A1 | A1 | A1 | A5 | A1 | A1 | A5 | A3 | A1 | A3 | A5 | A5 | A5 | A5 | A3 | A1 | A1 | A1 | A1 | A5 | A1 | A3 | A3 | A3 | A5 | A1 | A1 | A3 | 82 | Funcionamento estável | 82
2 | Funcionamento confiável | B | B1 | B | B1 | B1 | B1 | B1 | B5 | B5 | B1 | B5 | B3 | B5 | B3 | B3 | B5 | B5 | B3 | B5 | B3 | B1 | B1 | B1 | B3 | B3 | B1 | B3 | B3 | B3 | B3 | B3 | B3 | B3 | 87 | Funcionamento confiável | 87
3 | Alta TBO | C | A5 | B1 | C | D3 | E3 | F3 | G1 | H1 | I5 | C3 | C3 | C1 | M1 | N1 | C1 | C3 | C3 | C3 | S1 | T1 | U1 | V1 | W1 | C1 | Y1 | C1 | C3 | C3 | C5 | C1 | C1 | C1 | 33 | Alta TBO | 33
4 | Peças com baixo desgaste | D | A3 | B1 | D3 | D | E3 | F1 | D1 | D3 | I1 | J3 | D5 | D3 | D1 | D1 | D3 | D1 | D3 | D3 | D3 | T1 | U1 | V1 | W1 | D3 | Y1 | D1 | D1 | D3 | D5 | D1 | D1 | D1 | 46 | Peças com baixo desgaste | 46
5 | Componentes tecnologicamente confiáveis | E | A1 | B1 | E3 | E3 | E | E1 | E1 | E3 | I1 | E1 | E1 | E3 | E1 | E1 | E3 | E1 | E3 | E3 | E3 | E1 | E1 | E1 | E3 | E3 | E1 | E3 | E3 | E5 | E5 | E1 | E1 | E1 | 60 | Componentes tecnologicamente confiáveis | 60
6 | Potência desejada pelo comprador | F | A1 | B1 | F3 | F1 | E1 | F | F1 | F1 | F1 | F3 | F3 | F1 | F1 | F1 | F1 | F3 | F3 | F3 | S1 | T1 | U1 | V1 | W1 | F3 | F1 | F3 | F1 | F3 | F1 | F1 | F1 | F1 | 41 | Potência desejada pelo comprador | 41
7 | Gerenciado por ECU | G | A1 | B5 | G1 | D1 | E1 | F1 | G | H1 | I1 | G1 | G1 | G1 | M1 | N1 | G1 | G1 | G1 | G3 | S3 | T1 | U1 | G1 | W1 | G1 | Y1 | G3 | AA1 | G3 | G3 | G3 | AF1 | G3 | 41 | Gerenciado por ECU | 41
8 | Alta taxa de potência | H | A5 | B5 | H1 | D3 | E3 | F1 | H1 | H | I1 | H1 | H3 | H1 | H3 | H3 | H3 | H3 | H3 | H1 | S1 | T1 | U3 | V1 | W1 | H3 | H1 | H5 | AA1 | H1 | H3 | H5 | H1 | H5 | 47 | Alta taxa de potência | 47
9 | Baixo consumo horário | I | A1 | B1 | I5 | I1 | I1 | F1 | I1 | I1 | I | I5 | I5 | I3 | I3 | I5 | I3 | I5 | I5 | I5 | I1 | T1 | I1 | I3 | W1 | I5 | I1 | I5 | AA1 | I3 | I3 | I5 | I5 | I5 | 85 | Baixo consumo horário | 85
10 | Peças acessíveis no mercado | J | A1 | B5 | C3 | J3 | E1 | F3 | G1 | H1 | I5 | J | J1 | L1 | M1 | N1 | J1 | J3 | J3 | R1 | S3 | T1 | U3 | V3 | W1 | J3 | Y1 | J3 | AA1 | J1 | J3 | J1 | J1 | J1 | 24 | Peças acessíveis no mercado | 24
11 | Peças com valor adequado | K | A5 | B3 | C3 | D5 | E1 | F3 | G1 | H3 | I5 | J1 | K | L3 | M1 | K3 | K3 | K1 | K3 | K1 | S3 | T3 | U5 | V1 | W3 | K1 | Y3 | K3 | AA1 | K1 | K1 | K1 | K3 | K3 | 24 | Peças com valor adequado | 24
12 | Fácil manutenção | L | A3 | B5 | C1 | D3 | E3 | F1 | G1 | H1 | I3 | L1 | L3 | L | M1 | L3 | L5 | L5 | L5 | R1 | S3 | T3 | U3 | V1 | W1 | L3 | L1 | L3 | AA1 | L3 | L1 | L1 | L3 | L3 | 40 | Fácil manutenção | 40
13 | Intervalo prolongado entre manutenções | M | A1 | B3 | M1 | D1 | E1 | F1 | M1 | H3 | I3 | M1 | M1 | M1 | M | M3 | M5 | M3 | M3 | M1 | S3 | T1 | U1 | V1 | W1 | M5 | M1 | M3 | AA1 | M3 | AC1 | AD1 | M3 | M5 | 40 | Intervalo prolongado entre manutenções | 40
14 | Motor compacto | N | A3 | B3 | N1 | D1 | E1 | F1 | N1 | H3 | I5 | N1 | K3 | L3 | M3 | N | N3 | N3 | N3 | R1 | S3 | T3 | U5 | V1 | W3 | N1 | Y3 | N3 | AA3 | N1 | AC1 | N1 | N3 | N3 | 24 | Motor compacto | 24
15 | Fácil fabricação | O | A5 | B5 | C1 | D3 | E3 | F1 | G1 | H3 | I3 | J1 | K3 | L5 | M5 | N3 | O | O3 | Q3 | R3 | S5 | T3 | U5 | V3 | W5 | O1 | Y3 | O3 | AA3 | AB1 | AC3 | AD3 | AE1 | O3 | 10 | Fácil fabricação | 10
16 | Materia prima disponível e acessível no mercado nacional | P | A5 | B5 | C3 | D1 | E1 | F3 | G1 | H3 | I5 | J3 | K1 | L5 | M3 | N3 | O3 | P | Q3 | R1 | S5 | T5 | U5 | V3 | W3 | P5 | Y3 | P5 | AA3 | AB1 | AC1 | P3 | P5 | P5 | 23 | Materia prima disponível e acessível no mercado nacional | 23
17 | Processos simplificados | Q | A5 | B3 | C3 | D3 | E3 | F3 | G1 | H3 | I5 | J3 | K3 | L5 | M3 | N3 | Q3 | Q3 | Q | R3 | S5 | T5 | U5 | V3 | W3 | Q5 | Q1 | Q5 | AA1 | Q1 | AC1 | Q3 | Q5 | Q3 | 29 | Processos simplificados | 29
18 | Fácil acesso aos componentes (Acessibilidade para manutenção) | R | A5 | B5 | C3 | D3 | E3 | F3 | G3 | H1 | I5 | R1 | K1 | R1 | M1 | R1 | R3 | R1 | R3 | R | S5 | T5 | U5 | V3 | W3 | R3 | Y5 | R3 | AA5 | AB1 | AC1 | AD1 | R3 | R5 | 24 | Fácil acesso aos componentes (Acessibilidade para manutenção) | 24
19 | Robusto e durável | S | A3 | B3 | S1 | D3 | E3 | S1 | S3 | S1 | I1 | S3 | S3 | S3 | S3 | S3 | S5 | S5 | S5 | S5 | S | S1 | U1 | S1 | W1 | S3 | S3 | S5 | AA1 | S3 | S3 | S3 | S3 | S3 | 69 | Robusto e durável | 69
20 | Resistente a altas e baixas temperaturas | T | A1 | B1 | T1 | T1 | E1 | T1 | T1 | T1 | T1 | T1 | T3 | T3 | T1 | T3 | T3 | T5 | T5 | T5 | S1 | T | U5 | V1 | W5 | T5 | Y1 | T5 | AA1 | T1 | AC1 | AD1 | T1 | T1 | 48 | Resistente a altas e baixas temperaturas | 48
21 | Resistência mecânica e funcional | U | A1 | B1 | U1 | U1 | E1 | U1 | U1 | U3 | I1 | U3 | U5 | U3 | U1 | U5 | U5 | U5 | U5 | U5 | U1 | U5 | U | U5 | U1 | U5 | U1 | U5 | U1 | U5 | U3 | U3 | U5 | U5 | 89 | Resistência mecânica e funcional | 89
22 | Possibilidade de uso de combustíveis automotivos disponíveis no mercado | V | A1 | B1 | V1 | V1 | E1 | V1 | G1 | V1 | I3 | V3 | V1 | V1 | V1 | V1 | V3 | V3 | V3 | V3 | S1 | V1 | U5 | V | W3 | V5 | Y1 | V5 | V3 | V3 | V3 | V3 | V3 | V5 | 54 | Possibilidade de uso de combustíveis automotivos disponíveis no mercado | 54
23 | Flange de hélice compatível com hélices de mercado | W | A1 | B3 | W1 | W1 | E3 | W1 | W1 | W1 | W1 | W1 | W3 | W1 | W1 | W3 | W5 | W3 | W3 | W3 | W1 | W5 | U1 | W3 | W | W5 | W3 | W5 | AA1 | W3 | W3 | W3 | W3 | W3 | 66 | Flange de hélice compatível com hélices de mercado | 66
24 | Adequado a uma carenagem de motor para aeronave tandem ou lado a lado | X | A5 | B3 | C1 | D3 | E3 | F3 | G1 | H3 | I5 | J3 | K1 | L3 | M5 | N1 | O1 | P5 | Q5 | R3 | S3 | T5 | U5 | V5 | W5 | X | Y5 | Y1 | AA5 | AB1 | AC3 | AD3 | AE5 | AF3 | 0 | Adequado a uma carenagem de motor para aeronave tandem ou lado a lado | 0
25 | Maioria de peças compatíveis com motores automotivos | Y | A1 | B1 | Y1 | Y1 | E1 | F1 | Y1 | H1 | I1 | Y1 | Y3 | L1 | M1 | Y3 | Y3 | Y3 | Q1 | Y5 | S3 | Y1 | U1 | Y1 | W3 | Y5 | Y | Y3 | Y1 | AB1 | AC1 | Y1 | Y3 | Y1 | 37 | Maioria de peças compatíveis com motores automotivos | 37
26 | Mínimo conhecimento de motores exigido | Z | A3 | B3 | C1 | D1 | E3 | F3 | G3 | H5 | I5 | J3 | K3 | L3 | M3 | N3 | O3 | P5 | Q5 | R3 | S5 | T5 | U5 | V5 | W5 | Y1 | Y3 | Z | AA5 | AB5 | AC3 | AD1 | Z1 | Z1 | 2 | Mínimo conhecimento de motores exigido | 2
27 | Queimar combustível líquido | AA | A3 | B3 | C3 | D1 | E3 | F1 | AA1 | AA1 | AA1 | AA1 | AA1 | AA1 | AA1 | AA3 | AA3 | AA3 | AA1 | AA5 | AA1 | AA1 | U1 | V3 | AA1 | AA5 | Y1 | AA5 | AA | AA3 | AA1 | AA3 | AA3 | AA3 | 48 | Queimar combustível líquido | 48
28 | Sistema de acionamento simplificado | AB | A3 | B3 | C3 | D3 | E5 | F3 | G3 | H1 | I3 | J1 | K1 | L3 | M3 | N1 | AB1 | AB1 | Q1 | AB1 | S3 | T1 | U5 | V3 | W3 | AB1 | AB1 | AB5 | AA3 | AB | AC1 | AD1 | AB1 | AB1 | 12 | Sistema de acionamento simplificado | 12
29 | Sem controle manual de mistura e ponto | AC | A5 | B3 | C5 | D5 | E5 | F1 | G3 | H3 | I3 | J3 | K1 | L1 | AC1 | AC1 | AC3 | AC1 | AC1 | AC1 | S3 | AC1 | U3 | V3 | W3 | AC3 | AC1 | AC3 | AA1 | AC1 | AC | AC3 | AC3 | AC1 | 24 | Sem controle manual de mistura e ponto | 24
30 | Leitura de parâmetros do motor completa | AD | A1 | B3 | C1 | D1 | E1 | F1 | G3 | H5 | I5 | J1 | K1 | L1 | AD1 | N1 | AD3 | P3 | Q3 | AD1 | S3 | AD1 | U3 | V3 | W3 | AD3 | Y1 | AD1 | AA3 | AD1 | AC3 | AD | AE1 | AD1 | 12 | Leitura de parâmetros do motor completa | 12
31 | Baixo custo de produção | AE | A1 | B3 | C1 | D1 | E1 | F1 | AF1 | H1 | I5 | J1 | K3 | L3 | M3 | N3 | AE1 | P5 | Q5 | R3 | S3 | T1 | U5 | V3 | W3 | AE5 | Y3 | Z1 | AA3 | AB1 | AC3 | AE1 | AE | AF1 | 7 | Baixo custo de produção | 7
32 | Projeto desenvolvido com recursos disponíveis | AF | A3 | B3 | C1 | D1 | E1 | F1 | G3 | H5 | I5 | J1 | K3 | L3 | M5 | N3 | O3 | P5 | Q3 | R5 | S3 | T1 | U5 | V5 | W3 | AF3 | Y1 | Z1 | AA3 | AB1 | AC1 | AD1 | AF1 | AF | 4 | Projeto desenvolvido com recursos disponíveis | 4
 |  |  |  | 1 | Fraco
 |  |  |  | 3 | Médio
 |  |  |  | 5 | Forte
 |  |  | DIAGRAMA DE MUDGE
 | Requisitos dos clientes |  | A | B | C | D | E | F | G | H | I | J | K | L | M | N | O | P | Q | R | S | T | U | V | W | X | Y | Z | AA | AB | AC | AD | AE | AF | Total
1 | Funcionamento estável | A | A | B1 | A5 | A3 | A1 | A1 | A1 | A5 | A1 | A1 | A5 | A3 | A1 | A3 | A5 | A5 | A5 | A5 | A3 | A1 | A1 | A1 | A1 | A5 | A1 | A3 | A3 | A3 | A5 | A1 | A1 | A3 | 82
2 | Funcionamento confiável | B |  | B | B1 | B1 | B1 | B1 | B5 | B5 | B1 | B5 | B3 | B5 | B3 | B3 | B5 | B5 | B3 | B5 | B3 | B1 | B1 | B1 | B3 | B3 | B1 | B3 | B3 | B3 | B3 | B3 | B3 | B3 | 87
3 | Alta TBO | C |  |  | C | D3 | E3 | F3 | G1 | H1 | I5 | C3 | C3 | C1 | M1 | N1 | C1 | C3 | C3 | C3 | S1 | T1 | U1 | V1 | W1 | C1 | Y1 | C1 | C3 | C3 | C5 | C1 | C1 | C1 | 33
4 | Peças com baixo desgaste | D |  |  |  | D | E3 | F1 | D1 | D3 | I1 | J3 | D5 | D3 | D1 | D1 | D3 | D1 | D3 | D3 | D3 | T1 | U1 | V1 | W1 | D3 | Y1 | D1 | D1 | D3 | D5 | D1 | D1 | D1 | 46
5 | Componentes tecnologicamente confiáveis | E |  |  |  |  | E | E1 | E1 | E3 | I1 | E1 | E1 | E3 | E1 | E1 | E3 | E1 | E3 | E3 | E3 | E1 | E1 | E1 | E3 | E3 | E1 | E3 | E3 | E5 | E5 | E1 | E1 | E1 | 60
6 | Potência desejada pelo comprador | F |  |  |  |  |  | F | F1 | F1 | F1 | F3 | F3 | F1 | F1 | F1 | F1 | F3 | F3 | F3 | S1 | T1 | U1 | V1 | W1 | F3 | F1 | F3 | F1 | F3 | F1 | F1 | F1 | F1 | 41
7 | Gerenciado por ECU | G |  |  |  |  |  |  | G | H1 | I1 | G1 | G1 | G1 | M1 | N1 | G1 | G1 | G1 | G3 | S3 | T1 | U1 | G1 | W1 | G1 | Y1 | G3 | AA1 | G3 | G3 | G3 | AF1 | G3 | 27
8 | Alta taxa de potência | H |  |  |  |  |  |  |  | H | I1 | H1 | H3 | H1 | H3 | H3 | H3 | H3 | H3 | H1 | S1 | T1 | U3 | V1 | W1 | H3 | H1 | H5 | AA1 | H1 | H3 | H5 | H1 | H5 | 47
9 | Baixo consumo horário | I |  |  |  |  |  |  |  |  | I | I5 | I5 | I3 | I3 | I5 | I3 | I5 | I5 | I5 | I1 | T1 | I1 | I3 | W1 | I5 | I1 | I5 | AA1 | I3 | I3 | I5 | I5 | I5 | 85
10 | Peças acessíveis no mercado | J |  |  |  |  |  |  |  |  |  | J | J1 | L1 | M1 | N1 | J1 | J3 | J3 | R1 | S3 | T1 | U3 | V3 | W1 | J3 | Y1 | J3 | AA1 | J1 | J3 | J1 | J1 | J1 | 24
11 | Peças com valor adequado | K |  |  |  |  |  |  |  |  |  |  | K | L3 | M1 | K3 | K3 | K1 | K3 | K1 | S3 | T3 | U5 | V1 | W3 | K1 | Y3 | K3 | AA1 | K1 | K1 | K1 | K3 | K3 | 24
12 | Fácil manutenção | L |  |  |  |  |  |  |  |  |  |  |  | L | M1 | L3 | L5 | L5 | L5 | R1 | S3 | T3 | U3 | V1 | W1 | L3 | L1 | L3 | AA1 | L3 | L1 | L1 | L3 | L3 | 40
13 | Intervalo prolongado entre manutenções | M |  |  |  |  |  |  |  |  |  |  |  |  | M | M3 | M5 | M3 | M3 | M1 | S3 | T1 | U1 | V1 | W1 | M5 | M1 | M3 | AA1 | M3 | AC1 | AD1 | M3 | M5 | 40
14 | Motor compacto | N |  |  |  |  |  |  |  |  |  |  |  |  |  | N | N3 | N3 | N3 | R1 | S3 | T3 | U5 | V1 | W3 | N1 | Y3 | N3 | AA3 | N1 | AC1 | N1 | N3 | N3 | 24
15 | Fácil fabricação | O |  |  |  |  |  |  |  |  |  |  |  |  |  |  | O | O3 | Q3 | R3 | S5 | T3 | U5 | V3 | W5 | O1 | Y3 | O3 | AA3 | AB1 | AC3 | AD3 | AE1 | O3 | 10
16 | Materia prima disponível e acessível no mercado nacional | P |  |  |  |  |  |  |  |  |  |  |  |  |  |  |  | P | Q3 | R1 | S5 | T5 | U5 | V3 | W3 | P5 | Y3 | P5 | AA3 | AB1 | AC1 | P3 | P5 | P5 | 23
17 | Processos simplificados | Q |  |  |  |  |  |  |  |  |  |  |  |  |  |  |  |  | Q | R3 | S5 | T5 | U5 | V3 | W3 | Q5 | Q1 | Q5 | AA1 | Q1 | AC1 | Q3 | Q5 | Q3 | 29
18 | Fácil acesso aos componentes (Acessibilidade para manutenção) | R |  |  |  |  |  |  |  |  |  |  |  |  |  |  |  |  |  | R | S5 | T5 | U5 | V3 | W3 | R3 | Y5 | R3 | AA5 | AB1 | AC1 | AD1 | R3 | R5 | 24
19 | Robusto e durável | S |  |  |  |  |  |  |  |  |  |  |  |  |  |  |  |  |  |  | S | S1 | U1 | S1 | W1 | S3 | S3 | S5 | AA1 | S3 | S3 | S3 | S3 | S3 | 69
20 | Resistente a altas e baixas temperaturas | T |  |  |  |  |  |  |  |  |  |  |  |  |  |  |  |  |  |  |  | T | U5 | V1 | W5 | T5 | Y1 | T5 | AA1 | T1 | AC1 | AD1 | T1 | T1 | 48
21 | Resistência mecânica e funcional | U |  |  |  |  |  |  |  |  |  |  |  |  |  |  |  |  |  |  |  |  | U | U5 | U1 | U5 | U1 | U5 | U1 | U5 | U3 | U3 | U5 | U5 | 84
22 | Possibilidade de uso de combustíveis automotivos disponíveis no mercado | V |  |  |  |  |  |  |  |  |  |  |  |  |  |  |  |  |  |  |  |  |  | V | W3 | V5 | Y1 | V5 | V3 | V3 | V3 | V3 | V3 | V5 | 52
23 | Flange de hélice compatível com hélices de mercado | W |  |  |  |  |  |  |  |  |  |  |  |  |  |  |  |  |  |  |  |  |  |  | W | W5 | W3 | W5 | AA1 | W3 | W3 | W3 | W3 | W3 | 63
24 | Adequado a uma carenagem de motor para aeronave tandem ou lado a lado | X |  |  |  |  |  |  |  |  |  |  |  |  |  |  |  |  |  |  |  |  |  |  |  | X | Y5 | Y1 | AA5 | AB1 | AC3 | AD3 | AE5 | AF3 | 0
25 | Maioria de peças compatíveis com motores automotivos | Y |  |  |  |  |  |  |  |  |  |  |  |  |  |  |  |  |  |  |  |  |  |  |  |  | Y | Y3 | Y1 | AB1 | AC1 | Y1 | Y3 | Y1 | 37
26 | Mínimo conhecimento de motores exigido | Z |  |  |  |  |  |  |  |  |  |  |  |  |  |  |  |  |  |  |  |  |  |  |  |  |  | Z | AA5 | AB5 | AC3 | AD1 | Z1 | Z1 | 2
27 | Queimar combustível líquido | AA |  |  |  |  |  |  |  |  |  |  |  |  |  |  |  |  |  |  |  |  |  |  |  |  |  |  | AA | AA3 | AA1 | AA3 | AA3 | AA3 | 48
28 | Sistema de acionamento simplificado | AB |  |  |  |  |  |  |  |  |  |  |  |  |  |  |  |  |  |  |  |  |  |  |  |  |  |  |  | AB | AC1 | AD1 | AB1 | AB1 | 12
29 | Sem controle manual de mistura e ponto | AC |  |  |  |  |  |  |  |  |  |  |  |  |  |  |  |  |  |  |  |  |  |  |  |  |  |  |  |  | AC | AC3 | AC3 | AC1 | 24
30 | Leitura de parâmetros do motor completa | AD |  |  |  |  |  |  |  |  |  |  |  |  |  |  |  |  |  |  |  |  |  |  |  |  |  |  |  |  |  | AD | AE1 | AD1 | 12
31 | Baixo custo de produção | AE |  |  |  |  |  |  |  |  |  |  |  |  |  |  |  |  |  |  |  |  |  |  |  |  |  |  |  |  |  |  | AE | AF1 | 7
32 | Projeto desenvolvido com recursos disponíveis | AF |  |  |  |  |  |  |  |  |  |  |  |  |  |  |  |  |  |  |  |  |  |  |  |  |  |  |  |  |  |  |  | AF | 4
 | Valoração dos requisitos de clientes | Valor de importância
 | Funcionamento confiável | 87
 | Baixo consumo horário | 85
 | Resistência mecânica e funcional | 84
 | Funcionamento estável | 82
 | Robusto e durável | 69
 | Flange de hélice compatível com hélices de mercado | 63
 | Componentes tecnologicamente confiáveis | 60
 | Possibilidade de uso de combustíveis automotivos disponíveis no mercado | 52
 | Resistente a altas e baixas temperaturas | 48
 | Queimar combustível líquido | 48
 | Alta taxa de potência | 47
 | Peças com baixo desgaste | 46
 | Potência desejada pelo comprador | 41
 | Fácil manutenção | 40
 | Intervalo prolongado entre manutenções | 40
 | Maioria de peças compatíveis com motores automotivos | 37
 | Alta TBO | 33
 | Processos simplificados | 29
 | Gerenciado por ECU | 27
 | Peças acessíveis no mercado | 24
 | Peças com valor adequado | 24
 | Motor compacto | 24
 | Fácil acesso aos componentes (Acessibilidade para manutenção) | 24
 | Sem controle manual de mistura e ponto | 24
 | Materia prima disponível e acessível no mercado nacional | 23
 | Sistema de acionamento simplificado | 12
 | Leitura de parâmetros do motor completa | 12
 | Fácil fabricação | 10
 | Baixo custo de produção | 7
 | Projeto desenvolvido com recursos disponíveis | 4
 | Mínimo conhecimento de motores exigido | 2
 | Adequado a uma carenagem de motor para aeronave tandem ou lado a lado | 0

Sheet: 3 - Requisitos de projeto
Requisitos do cliente | Valoração dos requisitos do cliente | Requisitos do projeto
Funcionamento confiável | 87 | Sem falha no ciclo de combustão
 |  | Potência desejada no momento necessário
Baixo consumo horário | 85 | Consumir pouco combustível quando em operação de cruzeiro
Resistência mecânica e funcional | 84 | Peças com alta durabilidade
Funcionamento estável | 82 | Variação de rotação mínima para uma posição de borboleta estabelecida
 |  | Sem falha no ciclo de combustão
Robusto e durável | 69 | Manutenção de final de vida extendida
Flange de hélice compatível com hélices de mercado | 63 | Dimensões da flange conforme norma
Componentes tecnologicamente confiáveis | 60 | Componentes com certificação e reconhecidamente primeira linha (fornecedores com certificação ISO)
Possibilidade de uso de combustíveis automotivos disponíveis no mercado | 52 | Tipos de combustíveis comerciais
Resistente a altas e baixas temperaturas | 48 | temperaturas de trabalho considerando funcionamentos no verão e inverno em condições extremas
Queimar combustível líquido | 48 | Tipos de combustíveis comerciais
Alta taxa de potência | 47 | Alta potência por cm³
Peças com baixo desgaste | 46 | Peças com alta durabilidade
Potência desejada pelo comprador | 41 | Entregar a potência desejada no momento necessário
Fácil manutenção | 40 | Manutenção facilidada, tempo de execução e acessibilidade de componentes
Intervalo prolongado entre manutenções | 40 | Tempo prolongado entre manutenções
Maioria de peças compatíveis com motores automotivos | 37 | Número de peças compatíveis com mercado automotivo
Alta TBO (Time before opening - vida útil do motor antes de reformar) | 33 | Manutenção de final de vida extendida
Processos simplificados | 29 | Processos de fabricação convencionais e simplificados
Gerenciado por ECU | 27 | Gerenciamento eletrônico completo do motor com sistema redundante
Peças acessíveis no mercado | 24 | Pecas de reposição estarem disponíveis e acessíveis quando necessário
Peças com valor adequado | 24 | Peças com preço adequado a uma manutenção normal veicular
Motor compacto | 24 | Dimensões totais reduzidas
Fácil acesso aos componentes (Acessibilidade para manutenção) | 24 | Tempo necessário para manutenção
Sem controle manual de mistura e ponto | 24 | Número de controles no motor
Materia prima disponível e acessível no mercado nacional | 23 | Materia prima principal conhecida e disponível
Sistema de acionamento simplificado | 12 | Quantidade de procedimentos para acionamento
Leitura de parâmetros do motor completa | 12 | Número de parâmetros de leitura do motor
Fácil fabricação | 10 | Processos de fabricação convencionais e simplificados
Baixo custo de produção | 7 | Custo industrial
Projeto desenvolvido com recursos disponíveis | 4 | Equipe de projeto e hardware disponível na instituição
Mínimo conhecimento de motores exigido | 2 | Sem necessidade de treinamento específico para operação e manutenção
Adequado a uma carenagem de motor para aeronave tandem ou lado a lado | 0 | Dimensões totais reduzidas

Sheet: 4 - QFD
 |  | Requisitos de Projeto (COMO) | Sem falha no ciclo de combustão | Potência desejada no momento necessário | Consumir pouco combustível quando em operação de cruzeiro | Peças com alta durabilidade | Variação de rotação mínima para uma posição de borboleta estabelecida | Sem falha no ciclo de combustão | Dimensões da flange conforme norma | Componentes com certificação e reconhecidamente primeira linha (fornecedores com certificação ISSO / TS) | Temperaturas de trabalho considerando funcionamentos no verão e inverno em condições extremas | Tipos de combustíveis comerciais | Alta potência por cm³ | Peças com alta durabilidade | Entregar a potência desejada no momento necessário | Manutenção facilidada, tempo de execução e acessibilidade de componentes | Tempo prolongado entre manutenções | Número de peças compatíveis com mercado automotivo | Manutenção de final de vida extendida | Processos de fabricação convencionais e simplificados | Gerenciamento eletrônico completo do motor com sistema redundante | Pecas de reposição estarem disponíveis e acessíveis quando necessário | Peças com preço adequado a uma manutenção normal veicular | Dimensões totais reduzidas | Tempo necessário para manutenção | Número de controles no motor | Materia prima principal conhecida e disponível | Quantidade de procedimentos para acionamento | Número de parâmetros de leitura do motor | Custo industrial | Equipe de projeto e hardware disponível na instituição | Sem necessidade de treinamento específico para operação e manutenção | Dimensões totais reduzidas
 | Requisitos do cliente (O QUE) |  | 1 | 2 | 3 | 4 | 5 | 6 | 7 | 8 | 9 | 10 | 11 | 12 | 13 | 14 | 15 | 16 | 17 | 18 | 19 | 20 | 21 | 22 | 23 | 24 | 25 | 26 | 27 | 28 | 29 | 30 | 31
1 | Funcionamento confiável | 87 | 9 | 9 | 3 | 9 | 3 | 9 |  | 9 | 3 | 1 | 1 | 9 | 3 | 1 | 3 | 3 | 3 |  | 9 |  |  |  |  | 3 |  |  |  | 1
2 | Baixo consumo horário | 85 | 3 | 9 | 9 |  | 1 | 3 |  | 3 | 1 | 3 | 9 |  |  |  |  |  |  |  | 9 |  |  |  |  | 3 |  |  | 3 | 1 |  |  | 1
3 | Resistência mecânica e funcional | 84 | 1 | 1 |  | 9
4 | Funcionamento estável | 82
5 | Robusto e durável | 69
6 | Flange de hélice compatível com hélices de mercado | 63
7 | Componentes tecnologicamente confiáveis | 60
8 | Possibilidade de uso de combustíveis automotivos disponíveis no mercado | 52
9 | Resistente a altas e baixas temperaturas | 48
10 | Queimar combustível líquido | 48
11 | Alta taxa de potência | 47
12 | Peças com baixo desgaste | 46
13 | Potência desejada pelo comprador | 41
14 | Fácil manutenção | 40
15 | Intervalo prolongado entre manutenções | 40
16 | Maioria de peças compatíveis com motores automotivos | 37
17 | Alta TBO (Time before opening - vida útil do motor antes de reformar) | 33
18 | Processos simplificados | 29
19 | Gerenciado por ECU | 27
20 | Peças acessíveis no mercado | 24
21 | Peças com valor adequado | 24
22 | Motor compacto | 24
23 | Fácil acesso aos componentes (Acessibilidade para manutenção) | 24
24 | Sem controle manual de mistura e ponto | 24
25 | Materia prima disponível e acessível no mercado nacional | 23
26 | Sistema de acionamento simplificado | 12
27 | Leitura de parâmetros do motor completa | 12
28 | Fácil fabricação | 10
29 | Baixo custo de produção | 7
30 | Projeto desenvolvido com recursos disponíveis | 4
31 | Mínimo conhecimento de motores exigido | 2
32 | Adequado a uma carenagem de motor para aeronave tandem ou lado a lado | 0
 |  |  | 13 | 19 | 12 | 18 | 4 | 12 | 0 | 12 | 4 | 4 | 10 | 9 | 3 | 1 | 3 | 3 | 3 | 0 | 18 | 0 | 0 | 0 | 0 | 6 | 0 | 0 | 3 | 2 | 0 | 0 | 1

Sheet: 5 - Especificações de projeto
Pos. QFD | Requisitos do projeto | Valor meta
 | Sem falha no ciclo de combustão | Zero falha (medido pela taxa de variação da rotação, COVIMEP < 0,3)
 | Potência desejada no momento necessário | Potência: 100 < P < 120HP
 | Consumir pouco combustível quando em operação de cruzeiro | Consumo <= 18 l/h
 | Peças com alta durabilidade | Peças de reposição frequente >= 100h
 | Variação de rotação mínima para uma posição de borboleta estabelecida | Variação de rotação <= +\- 50 rpm
 | Sem falha no ciclo de combustão | Combustão em todos os ciclos
 | Manutenção de final de vida extendida | TBO >= 2000h
 | Dimensões da flange conforme norma | Flange conforme ASTM XPTO
 | Componentes com certificação e reconhecidamente primeira linha (fornecedores com certificação ISO/TS) | Peças de reposição que atendam norma ISO/TS
 | Tipos de combustíveis comerciais | Motor FLEX FUEL: Mogas, Avgas, Etanol
 | temperaturas de trabalho considerando funcionamentos no verão e inverno em condições extremas | Temp trabalho ambiente -10 < T < +50°C
 | Tipos de combustíveis comerciais | Motor FLEX FUEL: Mogas, Avgas, Etanol
 | Alta potência por cm³ | ??????????
 | Peças com alta durabilidade | Peças de reposição frequente >= 100h
 | Entregar a potência desejada no momento necessário
 | Manutenção facilidada, tempo de execução e acessibilidade de componentes | Manutenção básica realizada pelo operador, manual de manutenção detalhado
 | Tempo prolongado entre manutenções | Intervalo de mnt periódica >= 50h
 | Número de peças compatíveis com mercado automotivo | Possuir mais de 50% de paças compatíveis com mercado automotivo
 | Manutenção de final de vida extendida | TBO >= 2000h
 | Processos de fabricação convencionais e simplificados | Utilização de processos conhecidos e de domínio da equipe
 | Gerenciamento eletrônico completo do motor com sistema redundante | Utilização de ECU
 | Pecas de reposição estarem disponíveis e acessíveis quando necessário | Compra de peças no mercado local
 | Peças com preço adequado a uma manutenção normal veicular | Compra de peças no mercado local
 | Dimensões totais reduzidas | Packaging aproximado de LL x AA x CC
 | Tempo necessário para manutenção | Troca de óleo e velas <= 1h
 | Número de controles no motor | Controle de abertura de borboleta apenas
 | Materia prima principal conhecida e disponível | Alumínio, aço carbono, aço inox e demais matérias primas disponíveis
 | Quantidade de procedimentos para acionamento | Màximo de 2 procedimentos para acionamento do motor
 | Número de parâmetros de leitura do motor | Rotação, pressão e temp de óleo, pressão combustível, temp líq arrefecimento, EGT, map, lambda
 | Custo industrial
 | Equipe de projeto e hardware disponível na instituição | Projeto com pessoal e equipamento disponível na instituição
 | Sem necessidade de treinamento específico para operação e manutenção | Manutenção básica realizada pelo operador, manual de manutenção detalhado
 | Dimensões totais reduzidas | Packaging aproximado de LL x AA x CC

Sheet: Matriz morfológica
Funções elementares | Princípios de solução
 | 1 | 2 | 3 | 4
FA1. Sustentar
FA2. Locomover
FE1. AcopLar máquina
FE2. Regular ângulo de ataque
FE3.1. Introduzir orgão ativo
FE3.2. Regular Profundidade
FE3.3. Nivelar máquina
FE3.4. Deslocar solo lateralmente
FE4.1. Acionar módulo distribuidor
FE4.2. Incorporar semente
FE4.3. Incorporar fertilizante
FE5. Nivelar solo

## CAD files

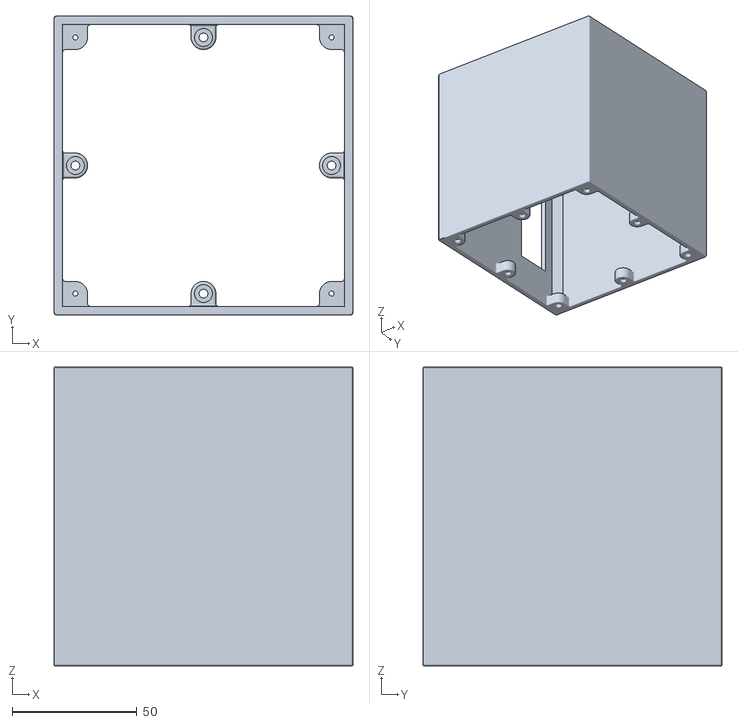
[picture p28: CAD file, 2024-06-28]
Modelagens/envio para impressão/EXA101/EXA101.STL
120.0 x 120.0 x 120.0

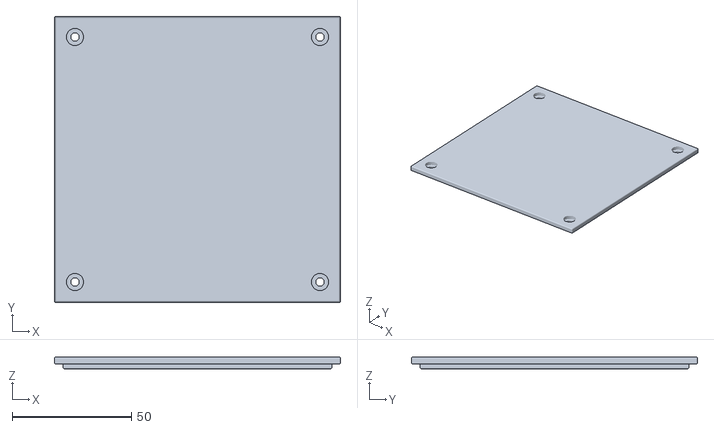
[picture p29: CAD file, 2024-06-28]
Modelagens/envio para impressão/EXA102/EXA102.STL
120.0 x 120.0 x 5.00

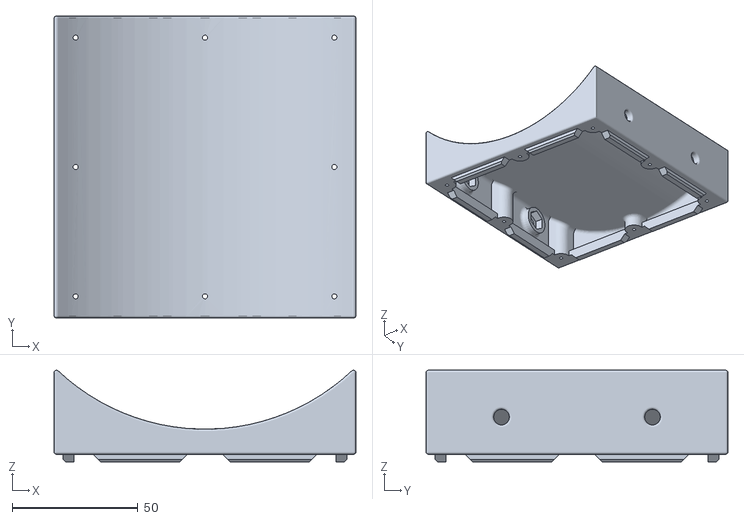
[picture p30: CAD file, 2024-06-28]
Modelagens/envio para impressão/EXA104/EXA104.STL
120.0 x 120.0 x 36.4

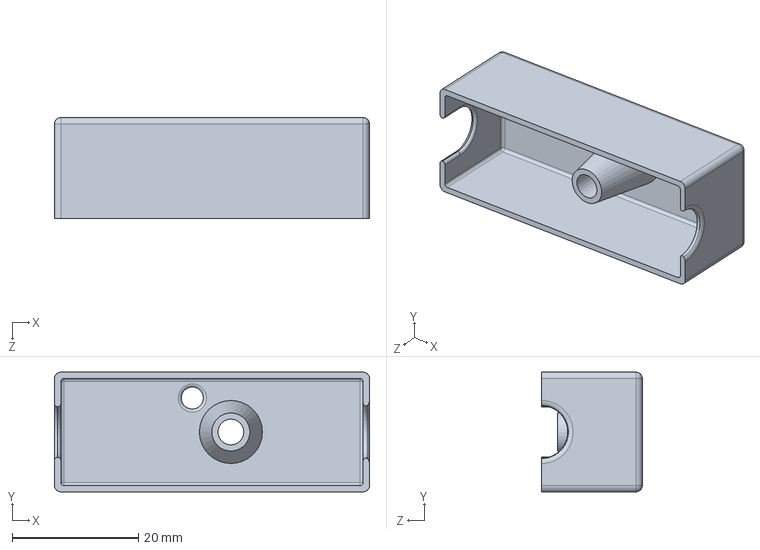
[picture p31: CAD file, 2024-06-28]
Modelagens/envio para impressão/EXA200/EXA200.SLDPRT
50.0 x 19.0 x 16.0 mm

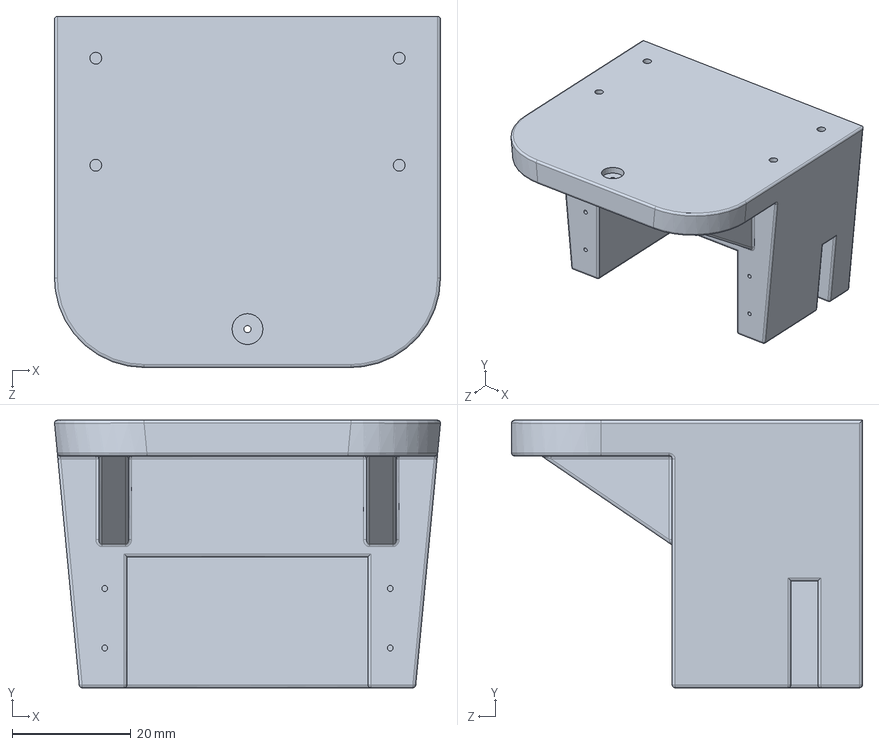
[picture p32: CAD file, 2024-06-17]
Modelagens/envio para impressão/EXA230/EXA230.SLDPRT
64.9 x 45.0 x 59.0 mm

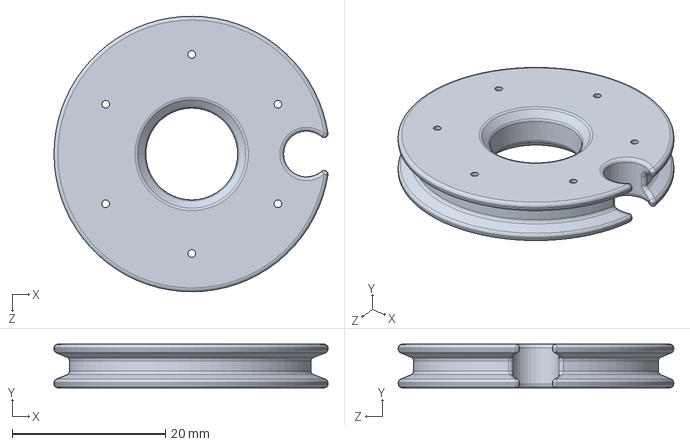
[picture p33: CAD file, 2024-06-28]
Modelagens/envio para impressão/EXA231/EXA231.SLDPRT
35.8 x 5.71 x 36.0 mm

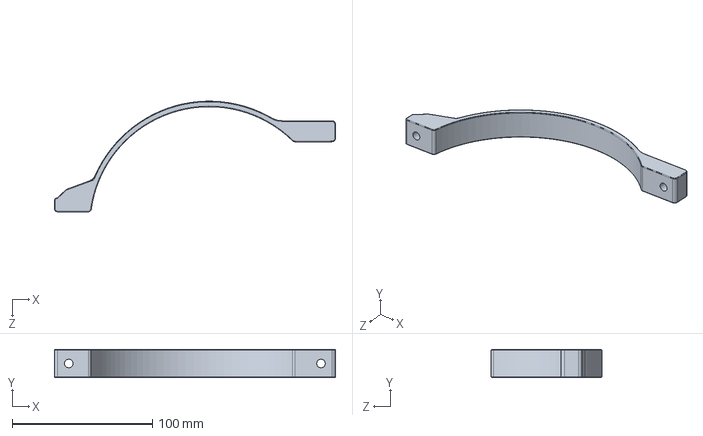
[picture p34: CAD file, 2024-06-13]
Modelagens/envio para impressão/EXA301/EXA301.SLDPRT
200.6 x 20.0 x 79.0 mm

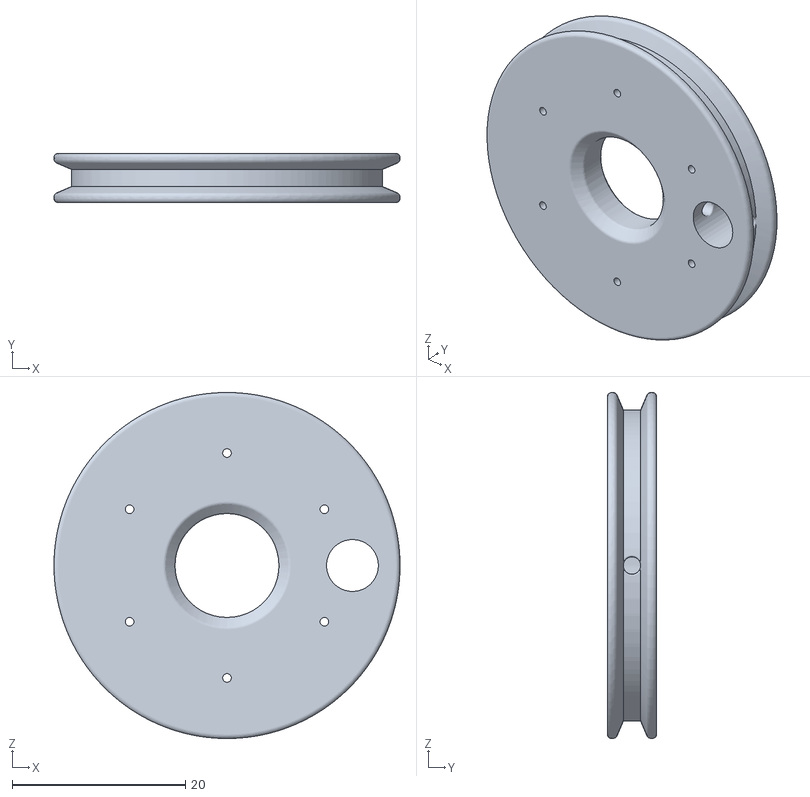
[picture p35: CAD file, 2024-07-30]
Modelagens/envio para impressão/Polia02.STL
40.0 x 5.71 x 40.0

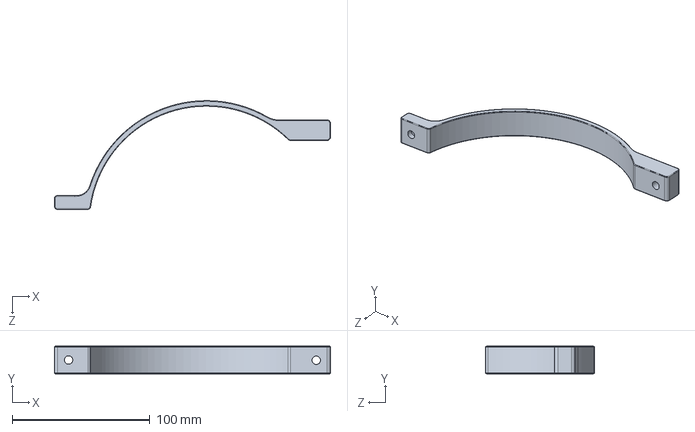
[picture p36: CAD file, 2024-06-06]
Modelagens/Marcus/EXA302.SLDPRT
200.6 x 20.0 x 79.0 mm

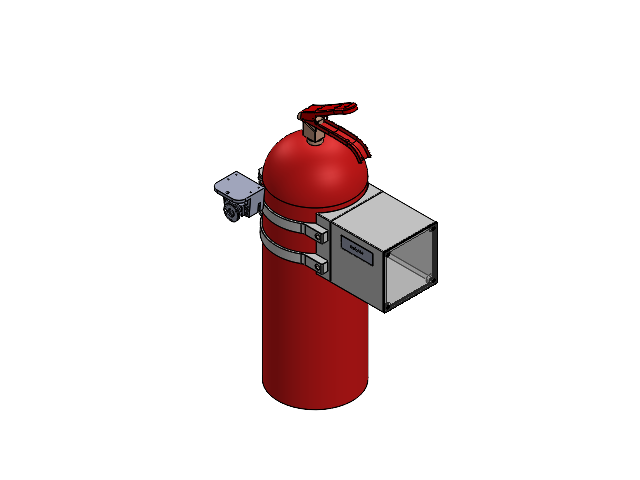
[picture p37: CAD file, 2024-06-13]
Modelagens/Mont1.SLDASM
EXA120
EXA121
EXA104
hex nut style 1_am x 6
EXA101
EXA102
socket head cap screw_am x 6
EXA115
EXA301 x 4
EXA222
EXA223
EXA230
EXA211
EXA231
EXA232

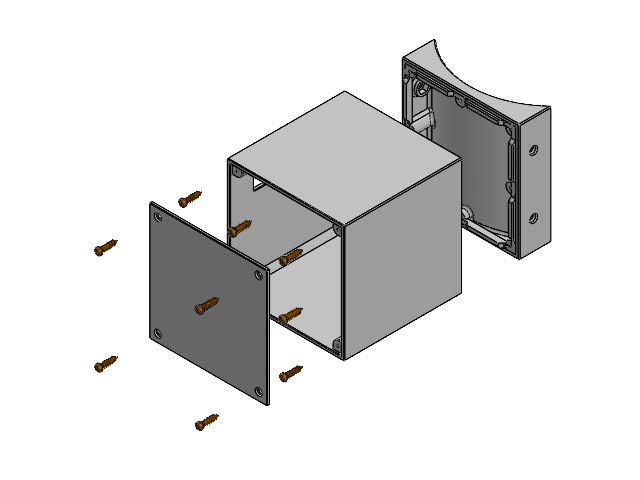
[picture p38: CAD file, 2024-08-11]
Modelagens/Rian/Mont2.SLDASM
EXA101
EXA104
EXA130 x 12
EXA102

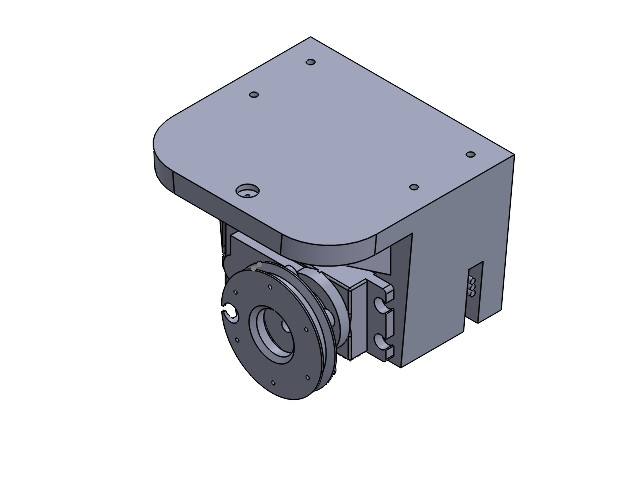
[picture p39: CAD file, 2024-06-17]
Modelagens/Tonetto/Montagem motor, polia, suporte.SLDASM
EXA230
EXA211
EXA231
EXA232

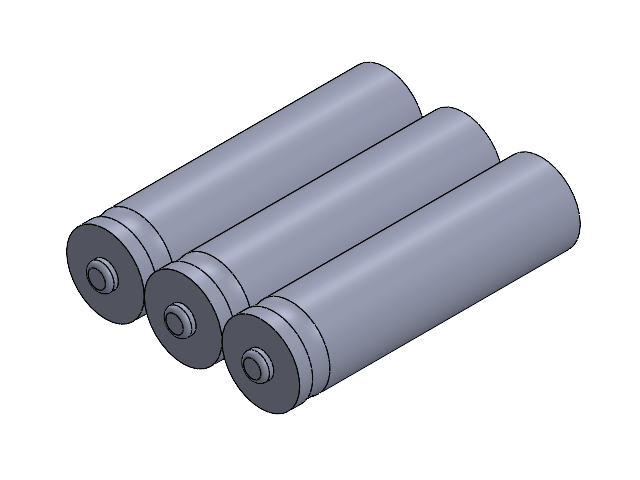
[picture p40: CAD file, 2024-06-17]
Modelagens/Rian/pack bateria.SLDASM
EXA210 x 3

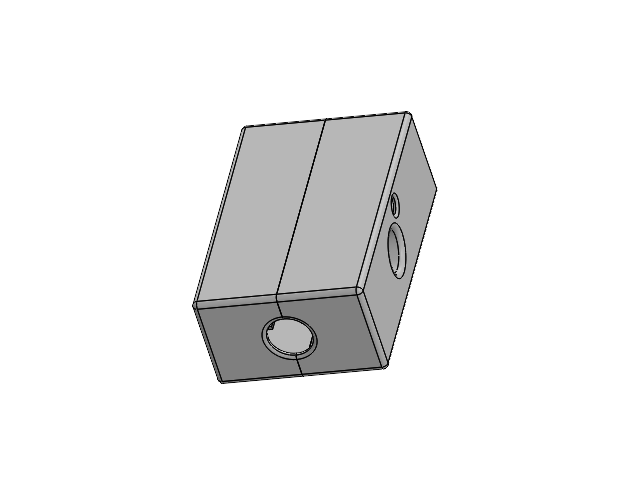
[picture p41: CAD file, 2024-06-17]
Modelagens/Tonetto/Montagem Suporte Sensores.SLDASM
EXA212
EXA213
EXA200 x 2

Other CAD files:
Modelagens/envio para impressão/Polia01.STL
Modelagens/Marcus/EXA301.SLDPRT
Modelagens/Rian/EXA231.SLDPRT
Modelagens/Marcus/EXA301.SLDDRW
Modelagens/Marcus/EXA_201.SLDPRT
Modelagens/Marcus/Peça1.SLDPRT
Modelagens/Rian/EXA101.SLDDRW
Modelagens/Rian/EXA101.SLDPRT
Modelagens/Rian/EXA102.SLDDRW
Modelagens/Rian/EXA102.SLDPRT
Modelagens/Rian/EXA104.SLDDRW
Modelagens/Rian/EXA104.SLDPRT
Modelagens/Rian/EXA115.SLDPRT
Modelagens/Rian/EXA120.SLDPRT
Modelagens/Rian/EXA121.SLDPRT
Modelagens/Rian/EXA130.SLDPRT
Modelagens/Rian/EXA131.SLDPRT
Modelagens/Rian/Mont2.SLDDRW
Modelagens/Tonetto/Cabo de aço.SLDPRT
Modelagens/Tonetto/Chaveiro Eng Eletrica.SLDPRT
Modelagens/Tonetto/DESENHO EXA230.SLDDRW
Modelagens/Tonetto/DESENHO EXA231.SLDDRW
Modelagens/Tonetto/Desenho EXA200.SLDDRW
Modelagens/Tonetto/EXA200.SLDPRT
Modelagens/Tonetto/EXA210.SLDPRT
Modelagens/Tonetto/EXA211.SLDPRT
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

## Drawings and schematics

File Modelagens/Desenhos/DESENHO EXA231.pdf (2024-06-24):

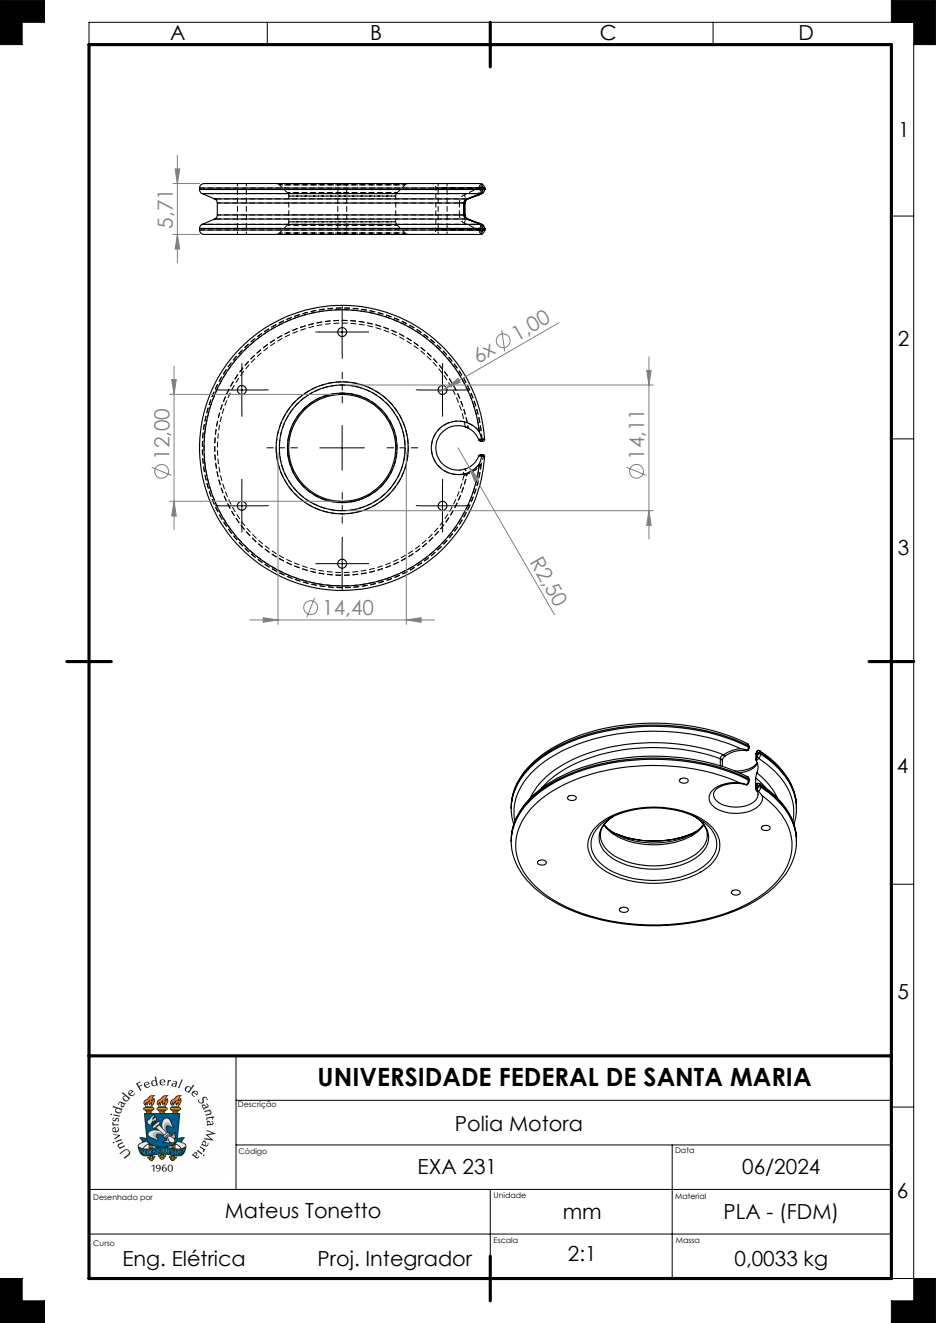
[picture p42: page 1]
Polia Motora

UNIVERSIDADE FEDERAL DE SANTA MARIA

Código EXA 231 | Data 06/2024

Desenhado por Mateus Tonetto | Unidade mm | Material PLA - (FDM)
Curso Eng. Elétrica Proj. Integrador | Escala 2:1 | Massa 0,0033 kg

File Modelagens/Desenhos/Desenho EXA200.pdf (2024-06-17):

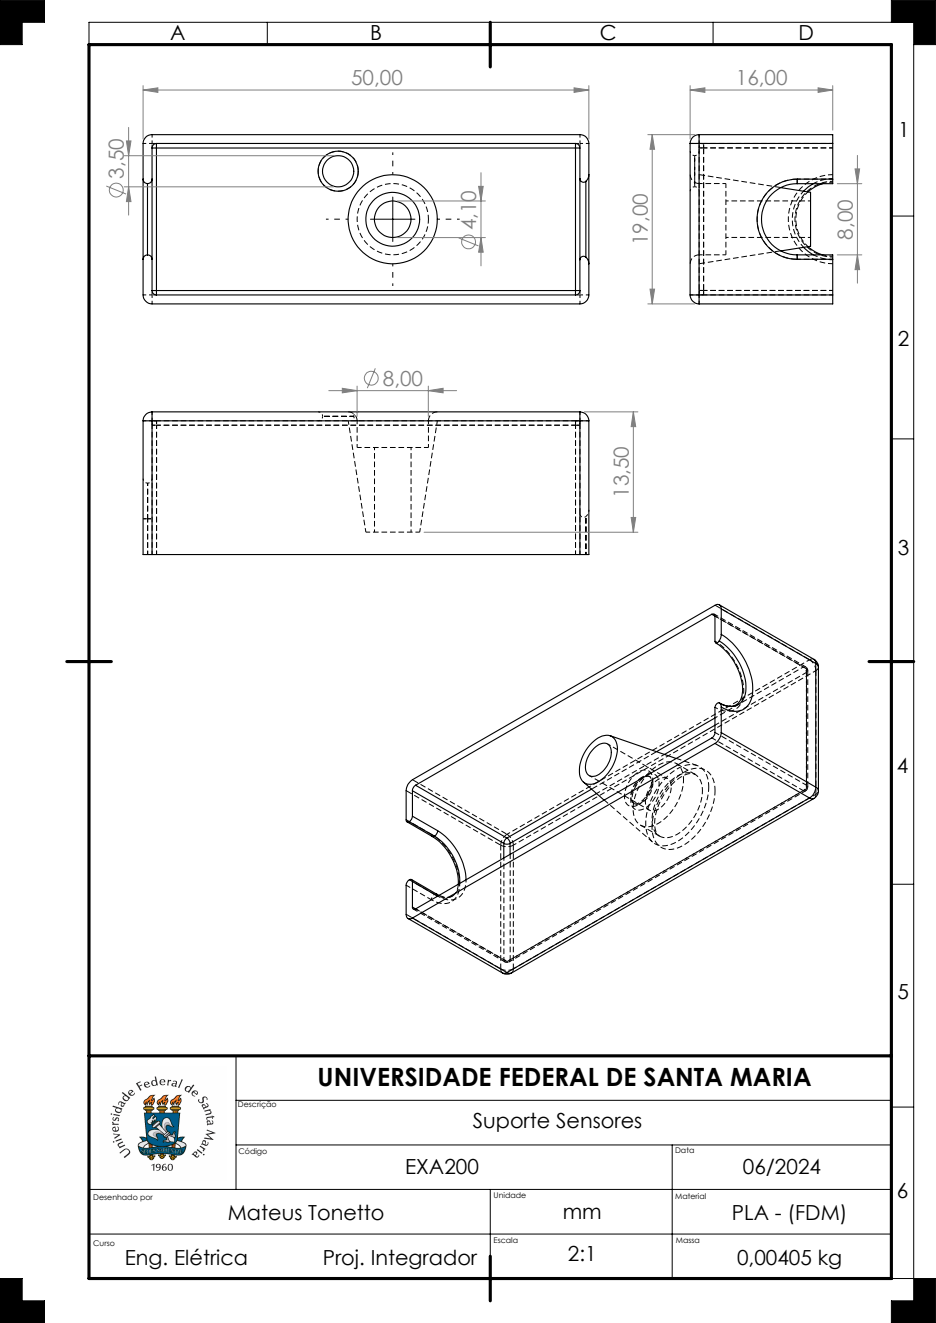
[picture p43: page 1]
Suporte Sensores

UNIVERSIDADE FEDERAL DE SANTA MARIA

Código EXA200 | Data 06/2024

Desenhado por Mateus Tonetto | Unidade mm | Material PLA - (FDM)
Curso Eng. Elétrica Proj. Integrador | Escala 2:1 | Massa 0,00405 kg

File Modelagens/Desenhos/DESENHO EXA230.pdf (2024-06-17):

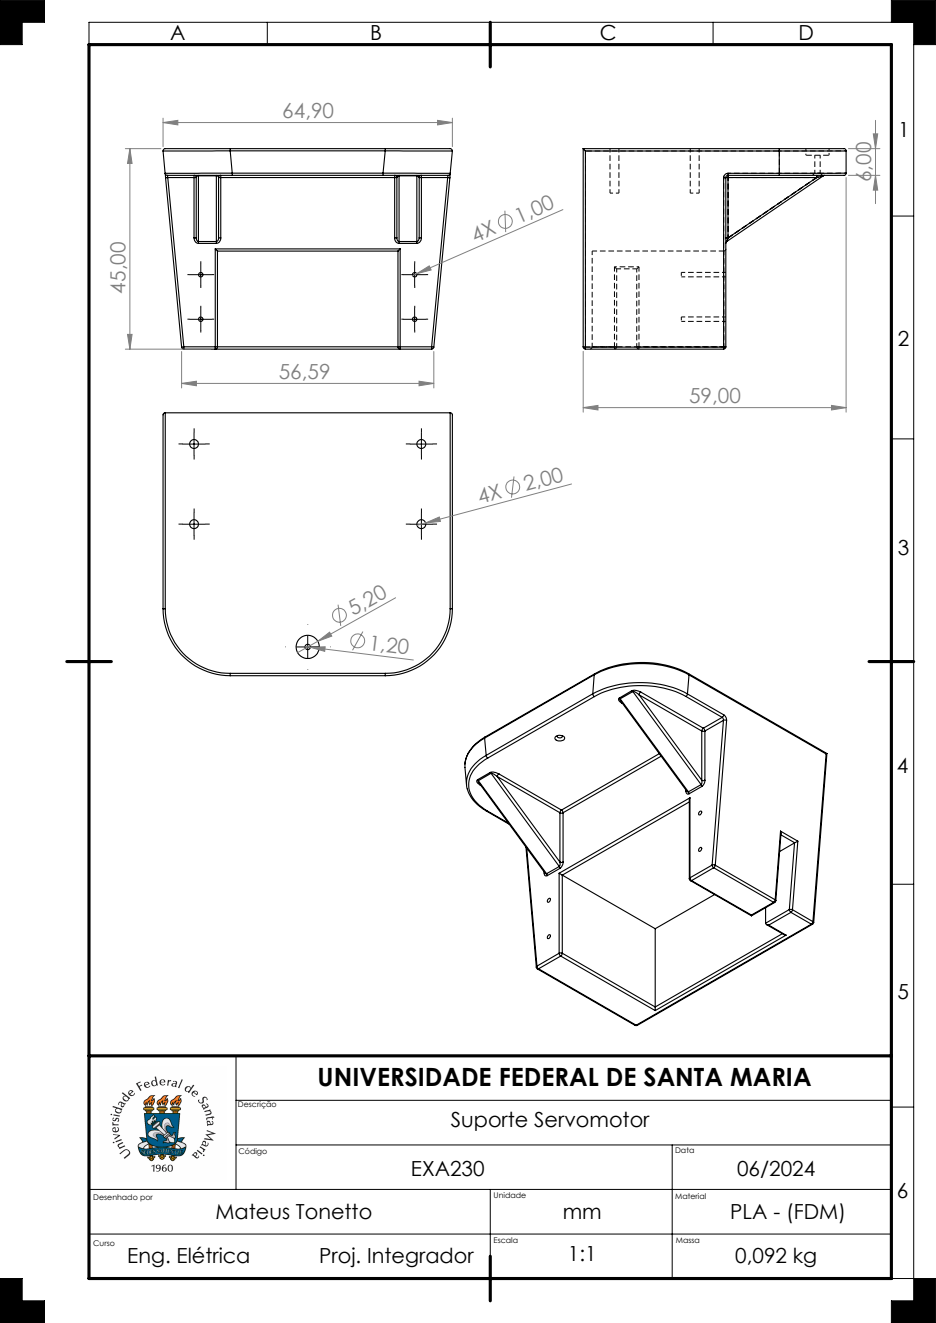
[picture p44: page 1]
Suporte Servomotor

UNIVERSIDADE FEDERAL DE SANTA MARIA

Código EXA230 | Data 06/2024

Desenhado por Mateus Tonetto | Unidade mm | Material PLA - (FDM)
Curso Eng. Elétrica Proj. Integrador | Escala 1:1 | Massa 0,092 kg

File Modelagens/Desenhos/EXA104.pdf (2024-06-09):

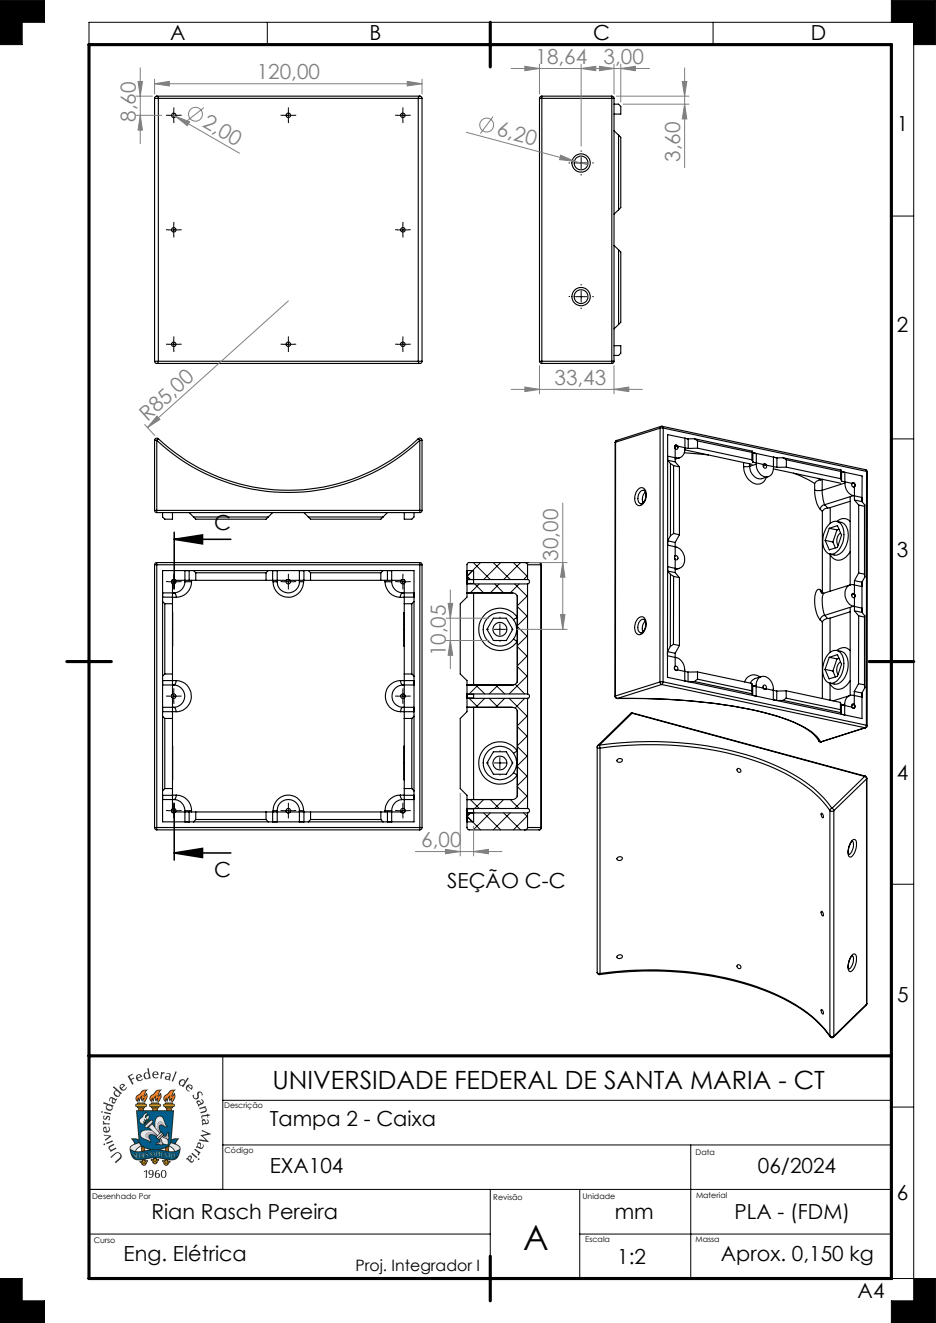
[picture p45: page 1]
SEÇÃO C-C

UNIVERSIDADE FEDERAL DE SANTA MARIA - CT
Tampa 2 - Caixa

Código EXA104 | Data 06/2024

Desenhado Por Rian Rasch Pereira | Revisão A | Unidade mm | Material PLA - (FDM)

Curso Eng. Elétrica Proj. Integrador I | | Escala 1:2 | Massa Aprox. 0,150 kg

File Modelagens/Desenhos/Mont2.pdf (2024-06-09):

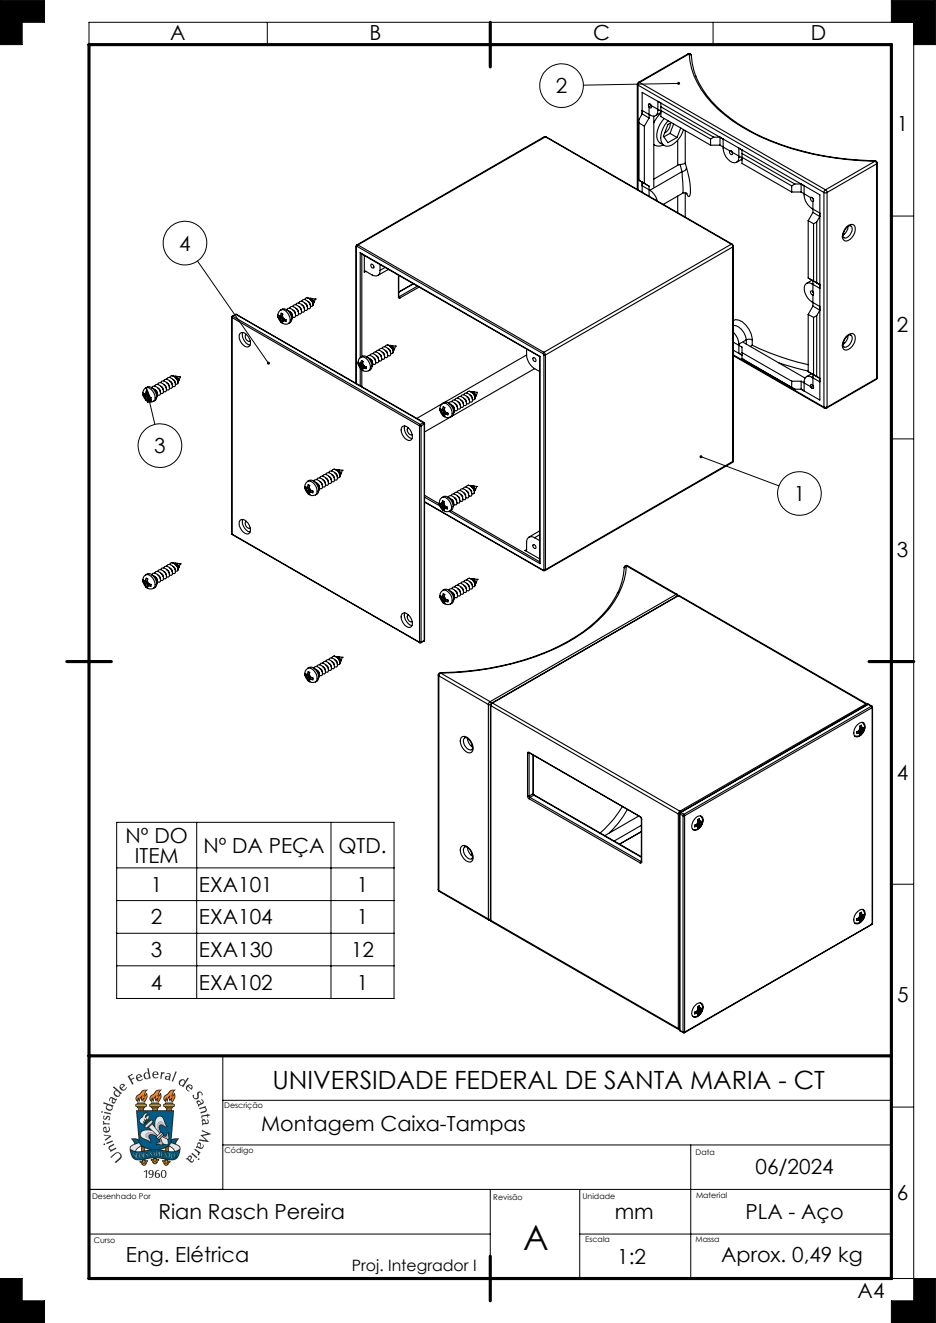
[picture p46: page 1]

Nº DO ITEM | Nº DA PEÇA | QTD.
1 | EXA101 | 1
2 | EXA104 | 1
3 | EXA130 | 12
4 | EXA102 | 1

UNIVERSIDADE FEDERAL DE SANTA MARIA - CT
Montagem Caixa-Tampas

Código | Data 06/2024

Desenhado Por Rian Rasch Pereira | Revisão A | Unidade mm | Material PLA - Aço

Curso Eng. Elétrica Proj. Integrador I | | Escala 1:2 | Massa Aprox. 0,49 kg

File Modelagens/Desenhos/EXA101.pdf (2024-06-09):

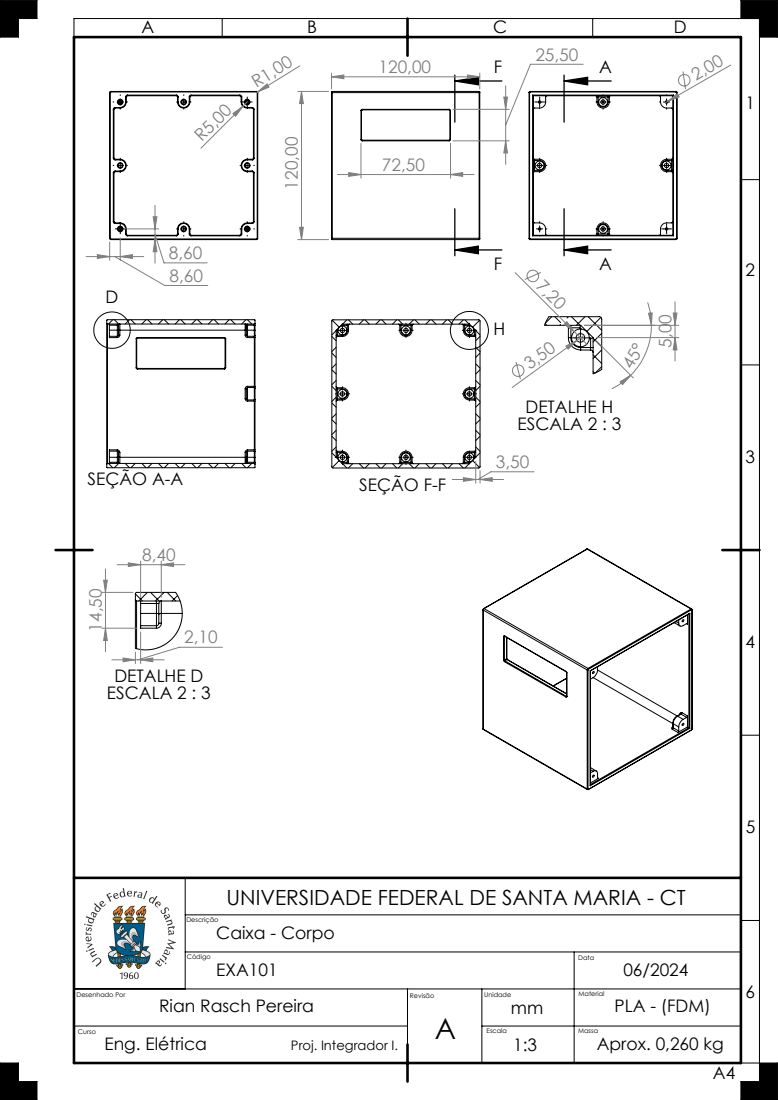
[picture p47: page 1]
SEÇÃO A-A 14,50; DETALHE D ESCALA 2 : 3; SEÇÃO F-F; DETALHE H ESCALA 2 : 3

UNIVERSIDADE FEDERAL DE SANTA MARIA - CT
Caixa - Corpo

Código EXA101 | Data 06/2024

Desenhado Por Rian Rasch Pereira | Revisão A | Unidade mm | Material PLA - (FDM)

Curso Eng. Elétrica Proj. Integrador I. | | Escala 1:3 | Massa Aprox. 0,260 kg

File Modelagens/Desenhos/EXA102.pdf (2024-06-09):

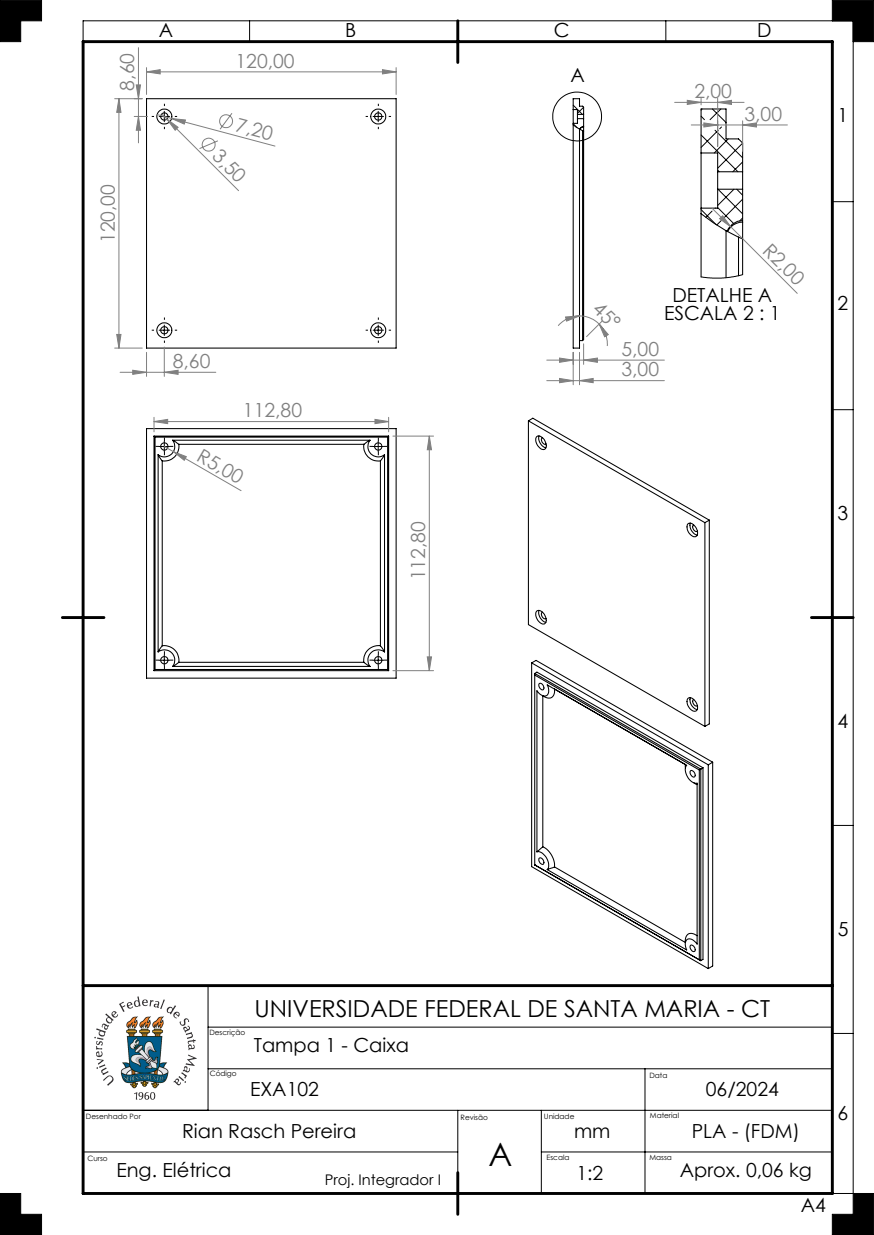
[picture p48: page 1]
DETALHE A ESCALA 2 : 1

UNIVERSIDADE FEDERAL DE SANTA MARIA - CT
Tampa 1 - Caixa

Código EXA102 | Data 06/2024

Desenhado Por Rian Rasch Pereira | Revisão A | Unidade mm | Material PLA - (FDM)

Curso Eng. Elétrica Proj. Integrador I | | Escala 1:2 | Massa Aprox. 0,06 kg

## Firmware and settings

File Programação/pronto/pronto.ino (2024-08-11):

#include <Wire.h>  
#include <LiquidCrystal_I2C.h>
#include <Servo.h>

#define flameSensorPin A0
#define tempSensorPin A1
#define batterySensorPin 2 
#define servoPin 3

#define p_temp 60
#define p_fogo 200 //0 a 1023
#define abertura 95
Servo servo;

LiquidCrystal_I2C lcd(0x27,20,4);

void setup() {
  //Serial.begin(9600);
  servo.attach(servoPin);
  pinMode(tempSensorPin, INPUT);
  pinMode(flameSensorPin, INPUT);
  servo.write(0);
  lcd.init(); 
  lcd.begin(16, 2); // Identifica que o display possui 16 colunas e 2 linhas
  lcd.clear(); // Apaga todos os caracteres do Display
  lcd.backlight();
}

int fogo_ir() {
  if (analogRead(flameSensorPin) < p_fogo) {
    delay(250);
    if (analogRead(flameSensorPin) < p_fogo) {
      return 1;
    } else return 0;
    }else return 0;
}

int fogo_temp() {
  int v_input = analogRead(tempSensorPin);//1024 VALUE
  float temp = 125.315-0.175529*v_input-2;
  if (temp > p_temp) {
    delay(250);
    int v_input = analogRead(tempSensorPin);//1024 VALUE
    float temp = 125.315-0.175529*v_input-2;
    if (temp > p_temp) {
      return 1;
    } else {
      return 0;
    }
  } else {
    return 0;
  }
}

void aciona_ext1(int flag){
  servo.write(abertura);
  while(flag !=0){
    delay(200);
    flag = fogo_temp() + fogo_ir(); 
  }
  servo.write(0);
}

void aciona_ext2(int flag){
  servo.write(abertura);
  delay(flag*1000);
  servo.write(0);
}

void loop() {
  int flag = fogo_temp() + fogo_ir();
  int v_input = analogRead(tempSensorPin);//1024 VALUE
  float temp = 125.315-0.175529*v_input-2;

/*
  Serial.print("Flag = ");
  Serial.println(flag);
  Serial.print("Temperatura: ");
  Serial.print(temp);
  Serial.println(" C ");
  Serial.print("IR: ");
  Serial.println(analogRead(flameSensorPin));
  Serial.print("Bat: ");
  Serial.print(map(analogRead(batterySensorPin), 0, 1023, 0, 100));
  Serial.println("%");
  Serial.println();
*/

  lcd.clear(); 
  lcd.setCursor(0,0); 
  lcd.print("Temp:");
  char buffer[10];
  dtostrf(temp, 3, 0, buffer);
  lcd.print(buffer);
  lcd.print("C");
  lcd.setCursor(0,1); 
  lcd.print("Bat:");
  dtostrf((2.54 + (analogRead(batterySensorPin) / 1023.0) * (4.25 - 2.54))*100/4.25, 3, 0, buffer);
  lcd.print(buffer);
  lcd.print("%");
  
  lcd.setCursor(10,0);
  lcd.print("Ir:");
  lcd.print(analogRead(flameSensorPin)/100);

   if(flag != 0){
    aciona_ext1(flag);
  }
  delay(500);
}

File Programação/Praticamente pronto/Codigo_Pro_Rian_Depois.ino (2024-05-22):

#include <Wire.h>  // Biblioteca para Comunicação I2C
#include <LiquidCrystal_I2C.h>  // Biblioteca com as funções do display
#include <Servo.h>

#define flameSensorPin A0
#define tempSensorPin A1
#define batterySensorPin A2 // Supondo que o sensor de carga da bateria está conectado ao pino A2
#define servoPin 3

#define p_temp 60
#define p_fogo 200
Servo servo;

LiquidCrystal_I2C lcd(0x27,20,4); // Inicializa o display no endereço 0x27

void setup() {
  Serial.begin(9600);
  servo.attach(servoPin);
  servo.write(0);
  lcd.init(); 
  lcd.begin(16, 2); // Identifica que o display possui 16 colunas e 2 linhas
  lcd.clear(); // Apaga todos os caracteres do Display
  lcd.backlight();
}

int fogo_ir() {
  if (analogRead(flameSensorPin) < p_fogo) {
    delay(250);
    if (analogRead(flameSensorPin) < p_fogo) {
      return 1;
    } else return 0;
    }
  } else {
    return 0;
  }
}

int fogo_temp() {
  if (map(analogRead(tempSensorPin), 0, 1023, 125, -55) > p_temp) {
    delay(250);
    if (map(analogRead(tempSensorPin), 0, 1023, 125, -55) > p_temp) {
      return 1;
    } else {
      return 0;
    }
  } else {
    return 0;
  }
}

void aciona_ext(int flag){
  int tempo = flag * 1000;
  servo.write(360);
  delay (tempo);
  servo.write(0);
}

void loop() {
  int flag = fogo_temp() + fogo_ir();
  
  Serial.print("Flag = ");
  Serial.println(flag);
  
  Serial.print("Temperatura: ");
  Serial.print(map(analogRead(tempSensorPin), 0, 1023, 125, -55));
  Serial.println(" C ");
  
  Serial.print("Bat: ");
  Serial.print(map(analogRead(batterySensorPin), 0, 1023, 0, 100));
  Serial.println("%");
  
  Serial.println();
  
  delay(1000);

  lcd.clear(); // Apaga todos os caracteres do Display
  lcd.setCursor(0,0); // Marca o cursor na posição coluna 0, linha 0
  lcd.print("Temperatura:");
  lcd.print(map(analogRead(tempSensorPin), 0, 1023, 125, -55));
  lcd.print("C");

  lcd.setCursor(0,1); // Marca o cursor na posição coluna 0, linha 1
  lcd.print("Bat:");
  lcd.print(map(analogRead(batterySensorPin), 0, 1023, 0, 100));
  lcd.print("%");
  lcd.print(" Ir: ");
  lcd.print(analogRead(flameSensorPin));
}

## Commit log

2024-05-22 Inserção de modelagens e organização
    Inserção dos primeiros arquivos de modelagens e definição de parte da organização do repositório
    [EXA101.SLDPRT, EXA102.SLDPRT, EXA103.SLDPRT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]
2024-05-24 minhas modelagens
    adicionei os modelos e os creditos
    [EXA210.SLDPRT, EXA211.SLDPRT, EXA220.SLDPRT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]
2024-05-24 tonetto modelagens
    e isso
    [EXA230.SLDPRT]
2024-05-27 Power point
    upload power point apresentação do trabalho
2024-05-28 commit alterações 27/05
    [EXA101.SLDPRT, EXA102.SLDPRT, EXA103.SLDPRT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]
2024-06-03 modelagens 03/06
    [EXA101.SLDPRT, EXA102.SLDPRT, EXA104.SLDPRT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]
2024-06-03 ajeitando arquivos
    [EXA103.SLDPRT, EXA120.SLDPRT, EXA121.SLDPRT]
2024-06-04 pecas novas
    pecas que peguei la na ufsm
    [EXA230.SLDPRT, EXA310.SLDPRT]
2024-06-06 modelagens 05/06
    [EXA112.SLDPRT, EXA301.SLDPRT, EXA302.SLDPRT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]
2024-06-07 trabalho dia 07/06
    [EXA104.SLDPRT, EXA115.SLDPRT, EXA190.SLDASM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]
2024-06-07 valvulas tonetto
    [EXA222.SLDPRT, EXA223.SLDPRT, EXA230.SLDPRT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]
2024-06-09 Dia 09/06
    [EXA101.SLDDRW, EXA101.SLDPRT, EXA102.SLDDRW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]
2024-06-09 final dia 09/06
    [EXA102.SLDDRW, EXA102.SLDPRT, EXA104.SLDDRW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]
2024-06-10 atualização
    [Servo Referencia (Nao usar).step.SLDPRT]
2024-06-10 imagens guia e suporte
    [EXA230.SLDPRT, Montagem motor, polia, suporte.SLDASM, Polia Servomotor.SLDPRT]
2024-06-10 atualização montagem
    [EXA231.SLDPRT, Mont1.SLDASM]
2024-06-10 estrela servo
    [EXA232.SLDPRT]
2024-06-11 tamanho da polia
    [EXA231.SLDPRT]
2024-06-12 atualização das montagem
    [EXA211.SLDPRT, EXA230.SLDPRT, EXA232.SLDPRT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]
2024-06-13 Envio do suporte do motor e polia
    [EXA230.SLDPRT, EXA230.STL, EXA231.SLDPRT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]
2024-06-17 suporte dos sensores
    [Desenho EXA200.SLDDRW, EXA200.SLDPRT, EXA212.SLDPRT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]
2024-06-24 ajuste polia
    [DESENHO EXA231.SLDDRW, EXA231.SLDPRT, EXA231.STL]
2024-06-27 Envio das peças para impressão
    Criação dos Stls, e .zip para envio das peças
    [EXA101.SLDPRT, EXA101.STL, EXA102.SLDPRT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]
2024-06-28 atualização poliaa
    [EXA231.SLDPRT]
2024-06-30 flame sensor
2024-06-30 arduino nano
2024-06-30 logo do curso
    [Logo 2mm.STL, dogtag.SLDPRT, dogtag.STL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]
2024-07-02 polia Rian
    [EXA231.SLDPRT]
2024-07-30 PoliasSTL
    DjTonetto
    [Polia01.STL, Polia02.STL]
2024-08-11 atualização preços componentes
    [Preços Componentes.xlsx]
2024-08-11 correção codigo
    [Mont2.SLDASM]
2024-08-12 EXA: Extintor automático contra incêndios
    Trabalho Final em padrão IEEE para a disciplina de Projeto Integrador para Engenharia Elétrica da UFSM
